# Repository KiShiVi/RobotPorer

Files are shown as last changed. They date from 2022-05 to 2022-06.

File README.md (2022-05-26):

# RobotPourer
Проект робота разливайки на Arduino. 

## Модель сборки

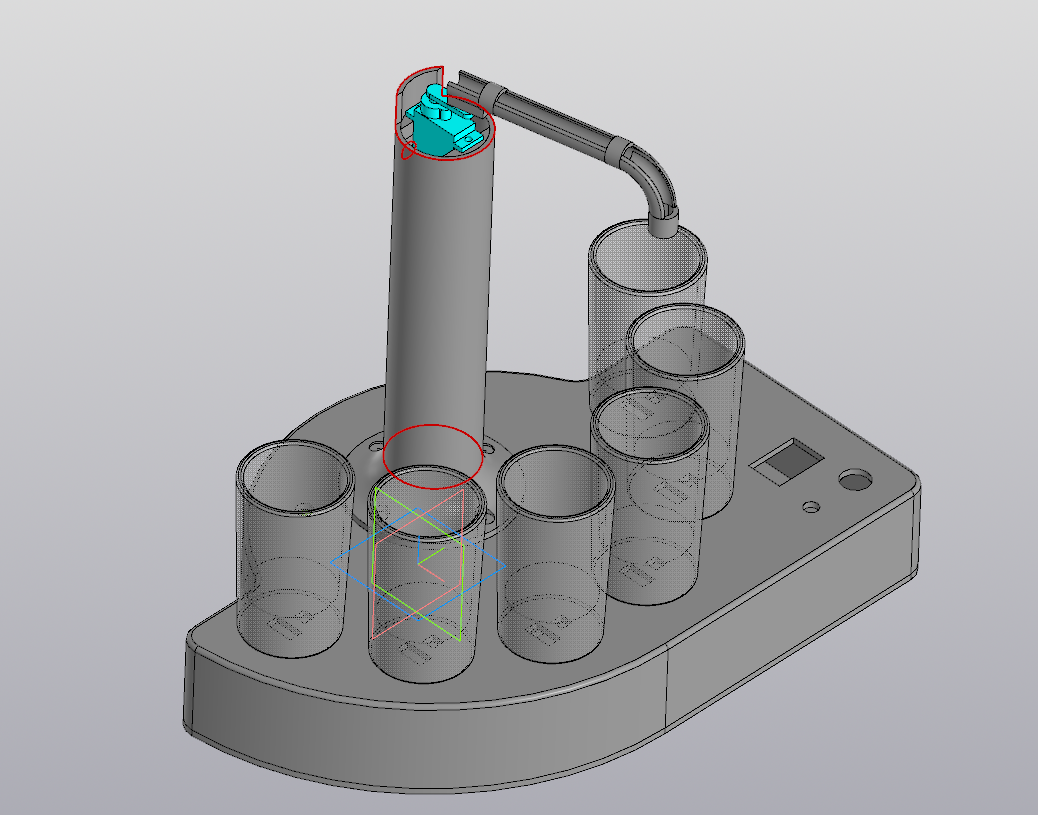
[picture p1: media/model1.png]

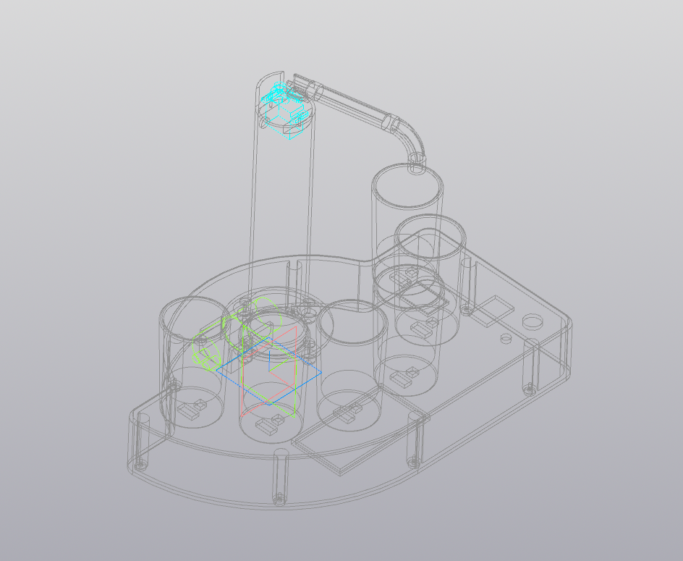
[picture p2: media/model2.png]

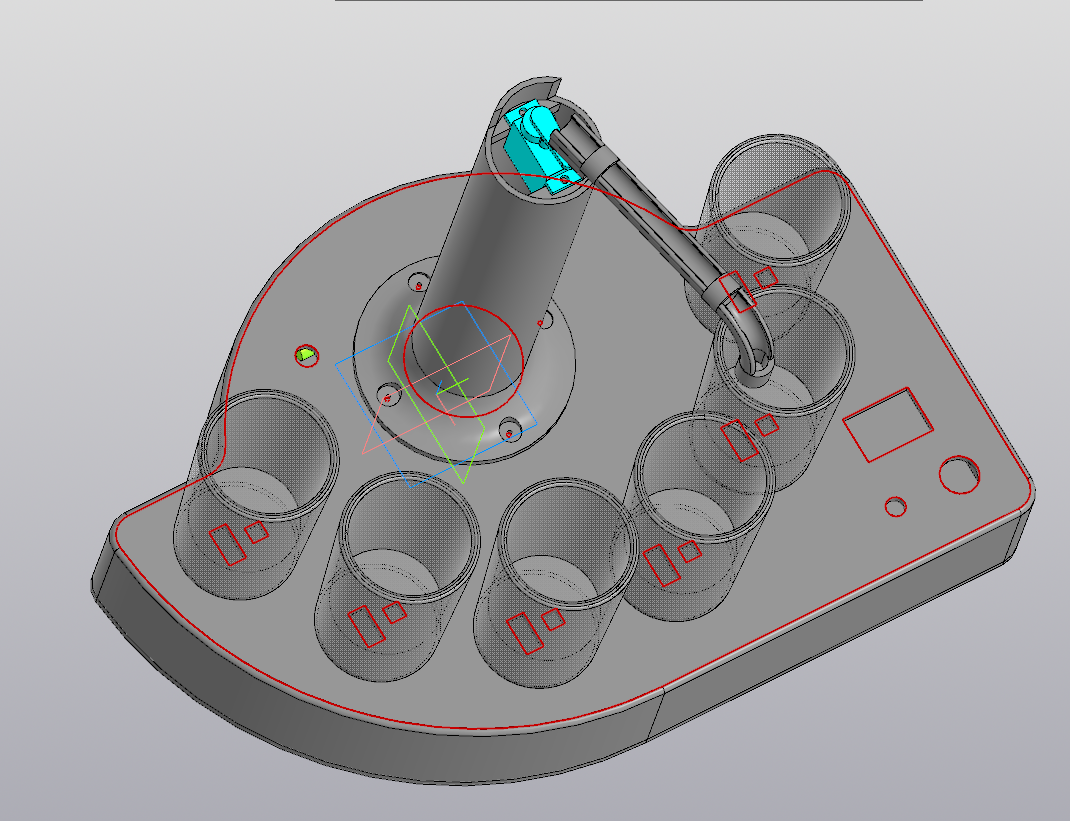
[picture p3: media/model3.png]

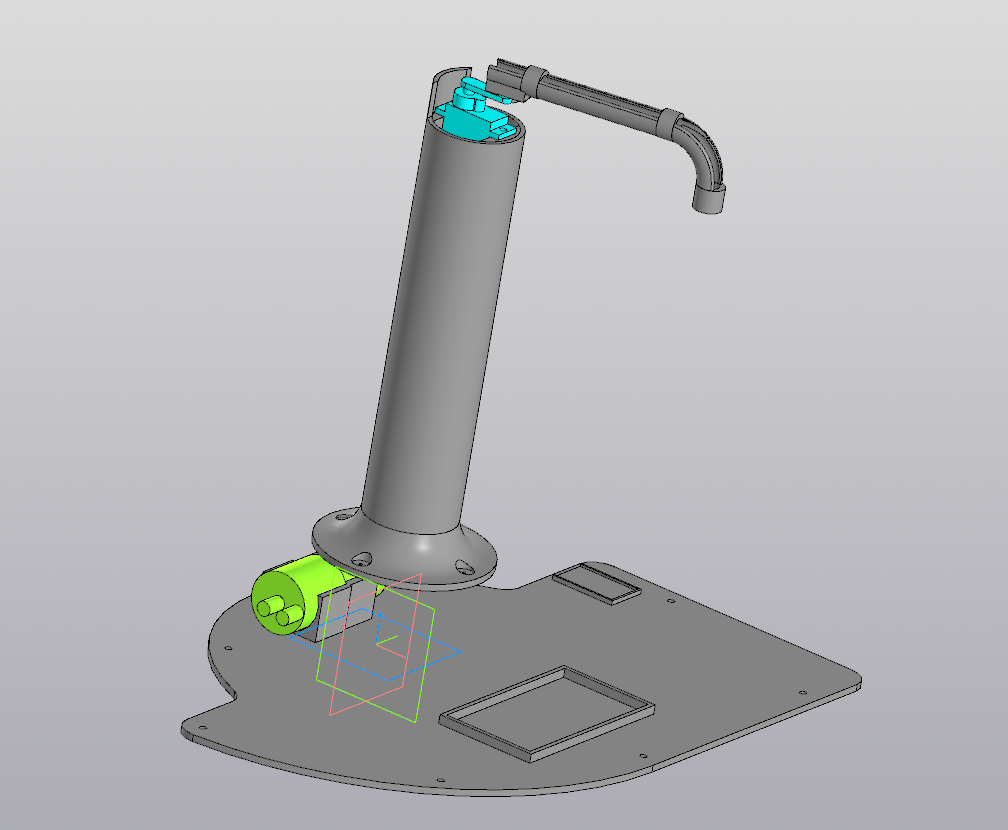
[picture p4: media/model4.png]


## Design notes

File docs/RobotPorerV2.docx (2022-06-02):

МИНОБРНАУКИ РОССИИ

САНКТ-ПЕТЕРБУРГСКИЙ ГОСУДАРСТВЕННЫЙ

ЭЛЕКТРОТЕХНИЧЕСКИЙ УНИВЕРСИТЕТ

«ЛЭТИ» ИМ. В.И. УЛЬЯНОВА (ЛЕНИНА)

Кафедра САПР

ОТЧЕТ

по курсовой работе

по дисциплине «Проектирование цифровых устройств»

Тема: Проектирование и реализация "робота-диспесора"

Студент гр. 9302 | | Тарабурин А.П.
Студент гр. 9302 | | Давтян С.Д.
Преподаватель | | Рыбин В.Г.

Санкт-Петербург

2022

АННОТАЦИЯ

Данная работа включает проектирование и реализацию «робота-диспенсора». В работе были использованы методы проектирование корпусов и схем, а также написан программный код для цифрового устройства. Кроме того, были доработаны и реализованы различные детали по улучшению работы данного робота.

В итоге корпус цифрового устройства был напечатан на 3D принтере, запрограммирован микроконтроллер, распаяна схема и собран робот.

ANNOTATION

This work includes the design and implementation of a "dispenser robot". The methods of designing cases and circuits were used in the work, and the program code for a digital device was written. In addition, various details have been finalized and implemented to improve the operation of this robot.

As a result, the body of the digital device was printed on a 3D printer, the microcontroller was programmed, the circuit was soldered, and the robot was assembled.

ОГЛАВЛЕНИЕ

# Цель работы

Изучить методы проектирование корпусов и схем, и научиться писать программный код для цифровых устройств

# Исходное задание

Необходимо реализовать цифровое устройство «робот-диспенсора», который будет разливать жидкость по сосудам, поставленным на обозначенные слоты со световой индикацией статусов. В роботе должны быть обозначены несколько режимов работы: автоматический, при котором разлив происходит без подтверждения пользователя; ручной, в котором разлив происходит только по нажатию кнопки, в выставленные рюмки; режим сервиса для отладки. Обеспечить пользователя информацией, которая будет водиться на OLED экран.

# Ход выполнения работы

# Принцип работы цифрового устройства

Робот-диспенсор (Рисунок 1) состоит из 4 частей. Отдельно были спроектированы корпус, крышка, стойка и краник. Каждая часть имеет свои особенности. Робот был собран с помощью соединения этих деталей.

Корпус содержит в себе множество отверстий. Под каждым слотом для рюмки есть по два отверстия, которые предназначены для адресного светодиода и концевика. Также отдельно есть отверстие прямоугольной формы для экрана и два круглых отверстия для энкодера и кнопки. Вдоль границ корпуса есть множество отверстий, которые предназначены для крепления крышки. Также есть два смежных отверстия: одно из них для стойки, другое – для прохождения сервопривода и силиконовой трубки. Силиконовая трубка через данное отверстие будет проходить к кранику (Рисунок 2).

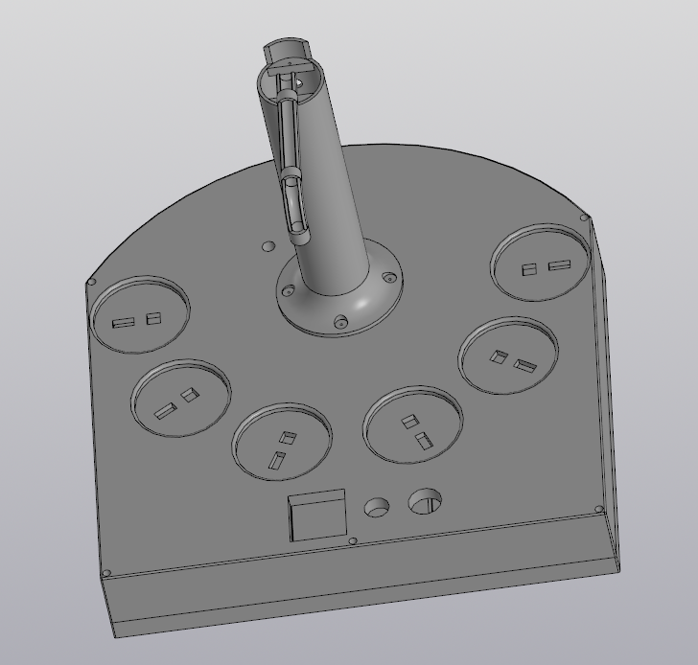
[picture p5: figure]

Рисунок 1. Робот-диспесор

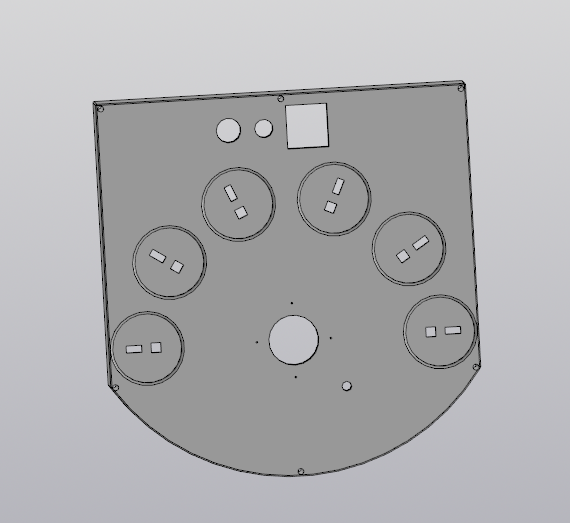
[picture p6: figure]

Рисунок 2. Корпус робота-диспесора

Стойка прикрепляется к корпусу. Для этого на ней предусмотрены четыре отверстия. Сама по себе она представляет из себя цилиндрический объект, через который проходит силиконовая трубка. Сверху есть крепление для сервопривода (Рисунок 3).

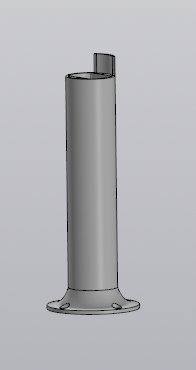
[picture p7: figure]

Рисунок 3. Стойка

Под корпусом находится крышка. Она крепится к корпусу с помощью саморезов. Для этого вдоль крышки сделаны отверстия. Также есть специальное крепление для водяной помпы (Рисунок 4).

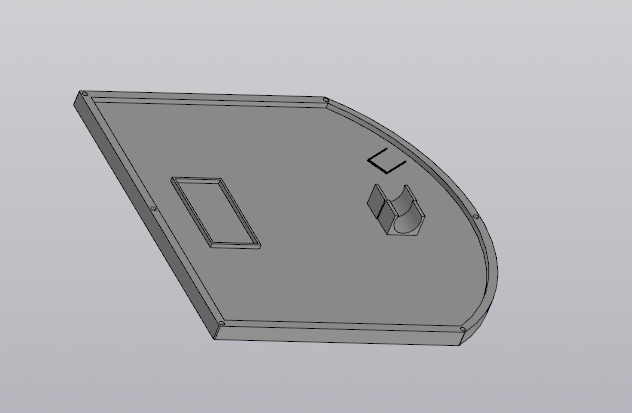
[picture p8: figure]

Рисунок 4. Крышка

Последняя часть робота-диспесора – краник. Он крепится к стойке. Для этого на нем сделаны отверстия. Через него будет поступать жидкость в рюмки (Рисунок 5).

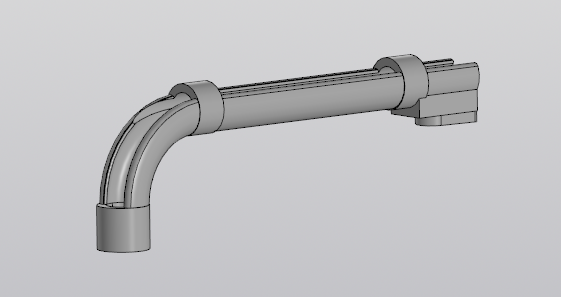
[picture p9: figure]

Рисунок 5. Краник

Описание схемы подключения

Схема подключения представлена на рисунках ниже (Рисунок 7, Рисунок 8, Рисунок 9, Рисунок 10)

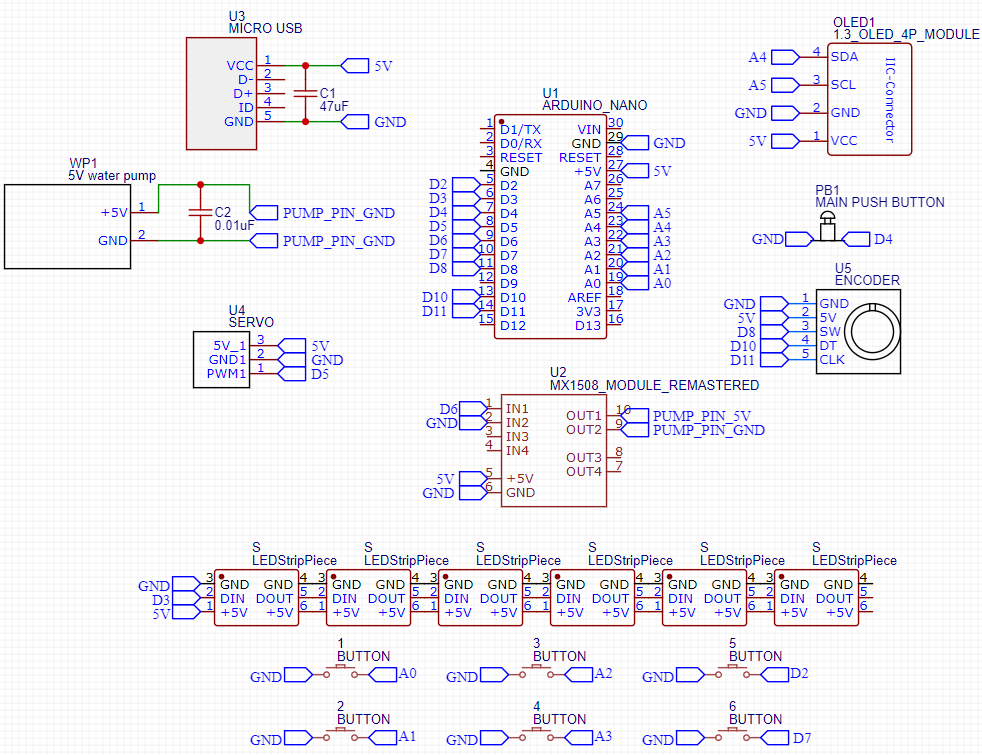
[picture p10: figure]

Рисунок 7

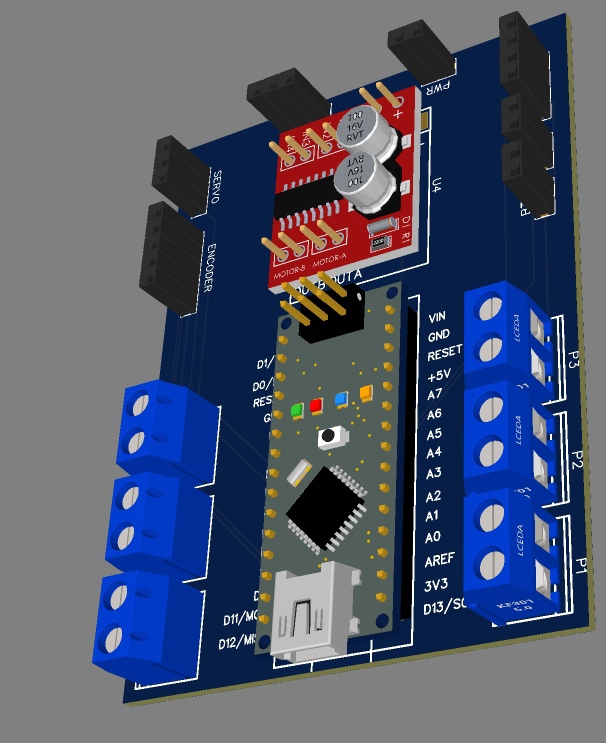
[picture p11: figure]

Рисунок 8

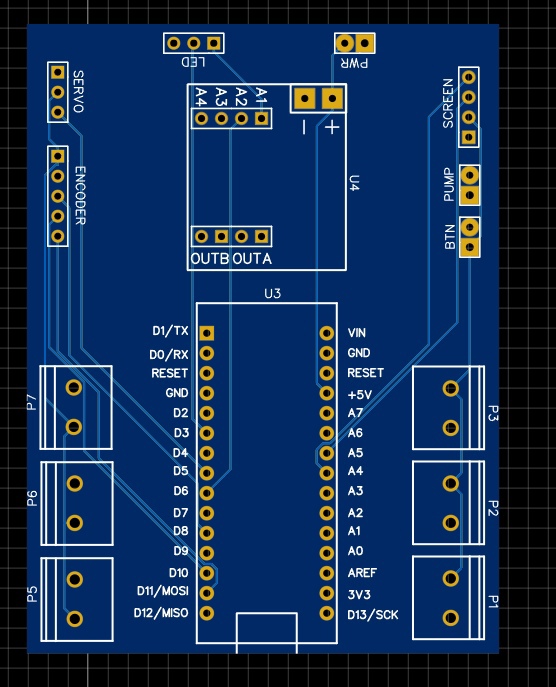
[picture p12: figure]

Рисунок 9

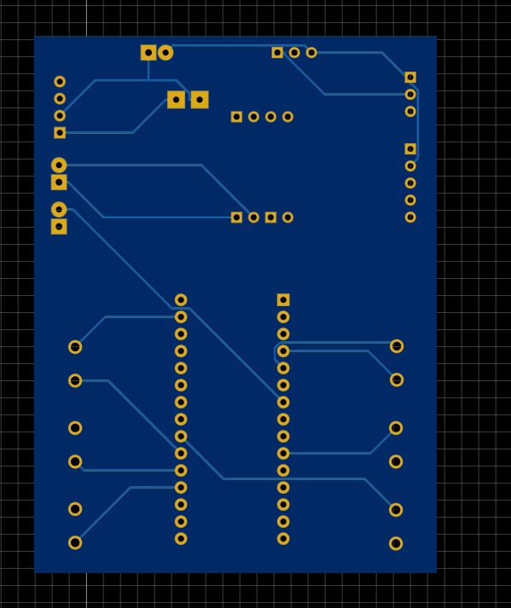
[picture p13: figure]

Рисунок 10

# Описание алгоритма работы устройства

Class Timer

Полями данного класса являются:

Интервал m_interval, хранящий значение, после которого можно перевести таймер в другое состояние;

Таймер m_timer показывает время начала работы в миллисекундах;

Состояние m_status отображает рабочее состояние таймера – true/false

Функция | Описание
Timer(uint32_t) | Конструктор от значения интервала
setInterval(uint32_t) | Установка значения интервала с проверкой на ненулевой аргумент
start() | Начало работы таймера, фиксирование текущего таймера и перевод состояния в рабочее
stop() | Завершение работы таймера, перевод в нерабочее состояние
boolean isReady() | Проверка готовности обрабатывания внешней функции с имеющимся интервалом и смещение существующего таймера к текущему значению времени, в диапазоне таймера
reset() | Обновление значения таймера до актуального
getState() | Получение состояния работы таймера

Class LedStrip

Полем класса ленты адресных светодиодов является массив leds класса CRGB, хранящий цвет подсветки имеющихся светодиодов

Функция | Описание
LedStrip () | Добавляем в массив LED_COUNT позиций светодиодов, выставляем яркость и изначальный цвет
ledOn( uint8_t pin, uint8_t r, uint8_t g, uint8_t b) | Выставляем цвет подсветки светодиоду в положении pin из цветовой модели RGB, параметры которой получаем из аргументов
ledOff( uint8_t) | Выставляем черный цвет подсветки светодиода в заданном положении, тем самым гася его

Class Pump

Полями класса помпы являются:

Таймер первоначальной задержки startDelayTimer, хранящий время задержки перед работой помпы;

Таймер окончательной задержки finishDelayTimer, хранящий время задержки после работы помпы;

Таймер окончания работы помпы finishTimer, показывающий время прекращения работы;

Состояние m_state, отображающее текущее рабочее состояние помпы BUSY/READY

Идентификатор пина m_pompPin, показывающий куда присоединено питание помпы

Функция | Описание
Pump(int) | Конструктор класса помпы от пина питания аппарата
pumpStart(uint32_t) | Старт работы помпы, перевод состояния в рабочее, установка заданного интервала для таймера окончания работы, запуск таймера первоначальной задержки
pumpStartWithoutTimer() | Начало работы помпы и перевод в рабочее состояние и запуск таймера первоначальной задержки
pumpStop( bool) | Остановка помпы, запуск таймера окончательной задержки и остановка остальных. Перевод в ожидающее состояние
getState() | Получение состояния работы помпы
isPouring() | Проверка накачивания жидкости в текущий момент при помощи проверки состояния таймера первоначальной задержки
isFinishedPoured () | Проверка завершения накачивания жидкости в текущий момент при помощи проверки состояния таймера окончания работы
pumpCheck() | Алгоритм приведения в работу помпы в зависимости от состояния одного из таймеров: При готовности таймера первоначальной задержки начинается накачивание жидкости При готовности таймера окончания работы останавливаем накачивание При готовности таймера окончательной задержки переводим помпу в режим ожидания

Class ServoCrane

Полями класса сервокраника являются:

Указатель на класс сервопривода Servo, хранящий методы работы с сервоприводами;

Значение m_currentAngle, хранящее текущий угол поворота краника относительно начальной позиции

Функция | Описание
ServoCrane (uint8_t) | Конструктор класса cервокраника с установкой пина питания сервопривода
rotate(uint8_t) | Поворот сервокраника на заданный угол с проверкой углов, выходящих за плоскость работы сервопривода
getCurrentAngle() | Получение текущего угла поворота сервокраника

Class Display

Поле класса дисплея является указатель на объект класса Adafruit_SSD1306, являющегося библиотечным классом для работы с нашим дисплеем.

Функция | Описание
Display () | Конструктор класса дисплея с очисткой, переводом курсора и заданием цвета шрифта. Выводит первоначальное приветствие
printRandToast() | Вывод случайного тоста из базы данных файла mem.hpp
printInfo(uint16_t volume, uint8_t mode) | Вывод количества наливаемого объема жидкости volume и текущего режима работы Робота-Наливайки mode

Class Slot

Полями класса слота для тары на корпусе робота являются:

Таймер работы кнопки подтверждения btnTimer, хранящий данные для ее работы;

Состояние кнопки btnState, обеспечивающее возможность ее нажатия;

Объекты ранее описанных классов сервокраника m_servo, помпы p_pump и ленты светодиодов p_ledStrip;

Номер пина концевика m_btnPin для обеспечения его питания;

Идентификатор слота m_slotID для передачи данных о нём вглубь алгоритма;

Значение угла поворота сервокраника к слоту m_slotAngle для поворота сервоприводом;

Состояние взаимодействия с тарой, размещенной на данном слоте, m_state - NO_GLASS, EMPTY, NEXT, PROCESS, READY;

Значение объема тары p_glassVolume, для регулирования процесса работы помпы.

Функция | Описание
Slot( LedStrip * ledStrip, Pump * pump, ServoCrane * servo, uint8_t btnPin, uint8_t slotID, uint8_t slotAngle, uint16_t * glassVolume ) | Конструктор класса слота с присвоением светодиода, помпы, сервокраника, установкой заданного номера пина концевика, идентификатора слота, угла поворота и объема тары. Состояние m_state изначально назначается NO_GLASS.
slotFirstCheck() | Первая проверка нажатия концевика слота. Включаем красный светодиод если рюмку только что поставили. Выключаем светодиод, если рюмку убрали. Меняем состояния.
slotSecondCheck() | Вторая проверка наливания стопки. Если статус слота PROCESS, ждем завершения таймера и перекрашиваем светодиод в зеленый. Меняем состояние на READY.
slotThirdCheck() | Третья проверка пустоты текущей рюмки. Если статус слота EMPTY поворачиваем сервокраник, в этот момент красим светодиод в синий, и начинаем наливать, попутно устанавливаем желтый цвет светодиоду. Меняем состояние на PROCESS.
getState() | Получение состояния слота.

Class Brain

Полями класса Brain, отвечающего за совмещение классов всех физических объектов и выполнение логики робота, являются:

Состояние робота m_mode, хранящее текущий режим работы робота MANUAL - ручной, AUTO - автоматический, SERVICE – сервисный;

Объем тары m_glassVolume, хранящий значение в миллилитрах;

Состояние m_status, показывающее текущую занятость робота BUSY, READY;

Логическая переменная m_toastFlag, отвечающее за возможность отображения тоста;

Логическая переменная isStarted, хранящий информацию о работе нового цикла робота;

Таймер начала работы p_starterTimer, отмеряющий время от запуска робота;

Значение текущего времени p_serviceTime, применяющееся для обработки нажатия сервисной кнопки;

Объекты ранее описанных классов сервокраника p_servo, помпы p_pump, ленты светодиодов p_ledStrip, дисплея p_display и массива слотов p_slots;

Указатели на библиотечные классы энкодера p_encoder и кнопки p_button;

Функция | Описание
Brain() | Конструктор по умолчанию с установкой ручного режима, объема тары 20 мл и всех прочих пинов питания
tick() | Срабатывает в loop .ino файла, здесь принимается решение о состоянии каждого слота, повороте сервокраника и отслеживании режима работы робота
changeAutoManualMode() | Изменение пользовательских режимов в зависимости от выбора
changeServiceMode() | Установка сервисного режима
incGlassVolume() | Увеличение объема тары от движения энкодера
decGlassVolume() | Уменьшение объема тары от движения энкодера
mainBtnPressed() | Обработчик длительного зажатия главной кнопки
mainBtnReleased() | Обработчик отпускания главной кнопки
mainBtnClick() | Обработчик нажатия главной кнопки
encClicked() | Обработчик нажатия энкодера, вызывающий отображение информации на главном экране

# Блок-схема алгоритма

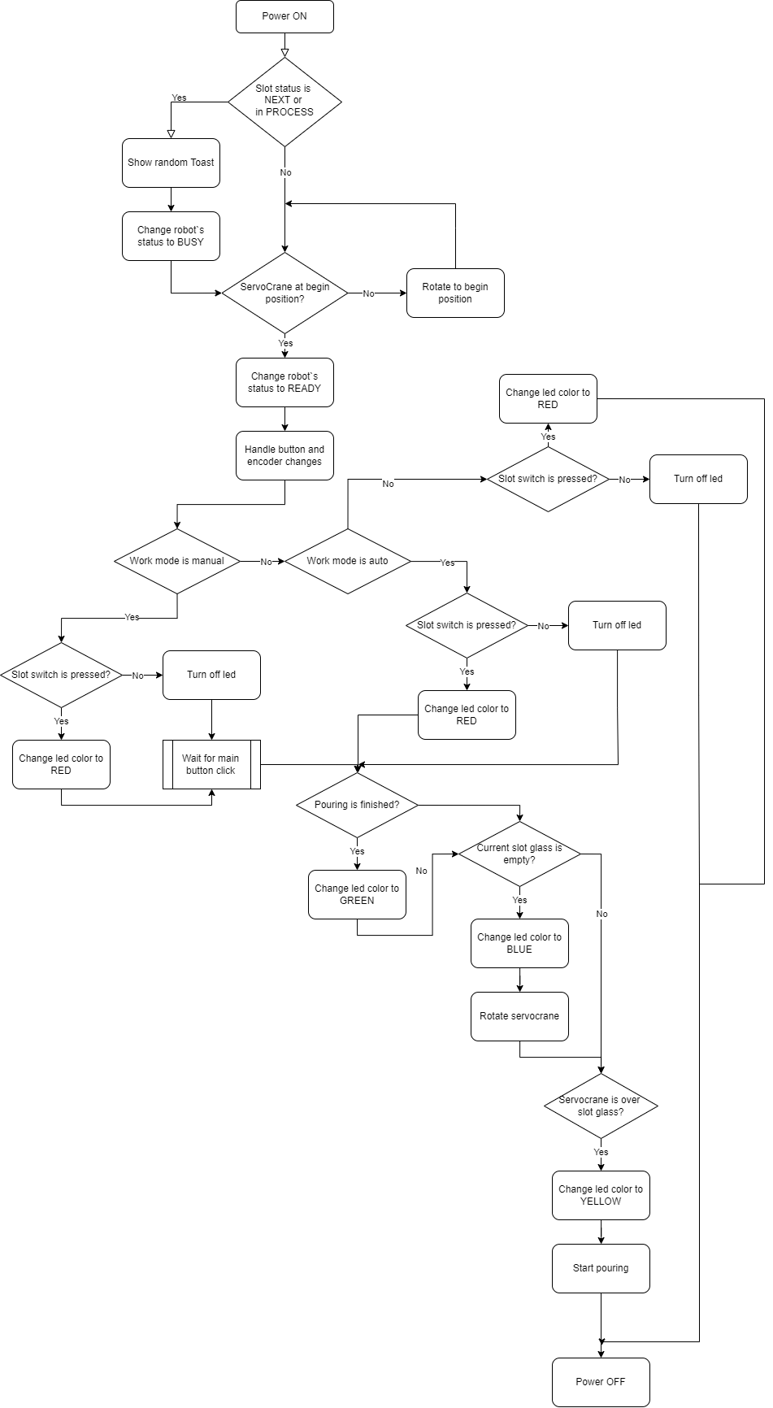
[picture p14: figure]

# ВЫВОД

В результате курсовой работы мы изучили методы проектирование корпусов и схем, и научились писать программный код для цифровых устройств.

А также мы реализовали цифровое устройство «робот-диспесора», который разливает жидкость в сосуды, поставленным на обозначенные слоты со световой индикацией статусов: красный, когда сосуд поставлен; синий, когда кран находиться над сосудом и скоро будет его наполнять; желтый, когда в сосуд наливается жидкость; зеленый, когда сосуд наполнили. В роботе обозначены несколько режимов работы: автоматический, при котором разлив происходит без подтверждения пользователя; ручной, в котором разлив происходит только по нажатию кнопки, в выставленные рюмки; режим сервиса для отладки. Еще мы обеспечили пользователя информацией, которая будет водиться на OLED экран, она включает в себя режим, угол движения крана, и тосты.

# СПИСОК ЛИТЕРАТУРЫ

1. Подбельский В. В. Язык C++ / В. В. Подбельский. — 3-е издание. — Москва : Финансы и статистика, 1998. — 560 c.
2. Макс Шлее Qt 5.10. Профессиональное программирование на C++ / Шлее Макс. — 1-е издание. — СПб : БХВ-Петербург, 2020. — 1072 c.
3. Герасимов, А. А. Самоучитель КОМПАС-3D V19 / А. А. Герасимов. — СПб : BHV, 2021. — 624 c. — Текст : непосредственный.

# ПРИЛОЖЕНИЕ

# Код программы

Timer.hpp

1. #ifndef TIMER_H
2. #define TIMER_H
4. /*
5. * Класс таймера
6. * Использован улучшенный алгоритм таймера на millis
7. * Обеспечивает кратные интервалы и защиту от пропусков и переполнений
8. *
9. */
10. class Timer
11. {
12. public:
13. Timer( uint32_t interval ); //!< Конструктор
14. void setInterval( uint32_t interval ); //!< Выставляет интервал срабатывания таймера
15. boolean isReady(); //!< Возвращает true, когда пришло время
16. void reset(); //!< Ручной сброс таймера
17. void stop(); //!< Остановка таймера
18. void start(); //!< Запуск таймера
19. bool getState();
21. private:
22. uint32_t m_timer = 0;
23. uint32_t m_interval = 0;
24. bool m_status = true;
25. };
27. Timer::Timer(uint32_t interval)
28. {
29. m_interval = interval;
30. m_timer = millis();
31. }
33. void Timer::setInterval(uint32_t interval)
34. {
35. m_interval = (interval == 0) ? 10 : interval;
36. }
38. void Timer::start()
39. {
40. m_status = true;
41. m_timer = millis();
42. }
44. void Timer::stop()
45. {
46. m_status = false;
47. }
49. boolean Timer::isReady()
50. {
51. uint32_t thisMls = millis();
52. if (m_status && thisMls - m_timer >= m_interval)
53. {
54. do
55. {
56. m_timer += m_interval;
57. if (m_timer < m_interval) break;
58. } while (m_timer < thisMls - m_interval);
59. return true;
60. }
61. else
62. {
63. return false;
64. }
65. }
67. void Timer::reset() {
68. m_timer = millis();
69. }
71. bool Timer::getState()
72. {
73. return m_status;
74. }
76. #endif

ledStrip.hpp

1. #ifndef LED_STRIP_H
2. #define LED_STRIP_H
4. #include "settings.hpp"
5. #include <FastLED.h>
7. /*
8. * Класс ленты адресных светодиодов
9. *
10. */
13. class LedStrip
14. {
15. public:
16. LedStrip(); //!< Конструктор
17. void ledOn( uint8_t pin, uint8_t r, uint8_t g, uint8_t b ); //!< Включить светодиод. pin - позиция светодиода. r/g/b - цвет (0-255)
18. void ledOff( uint8_t pin ); //!< Выключить светодиод. pin - позиция светодиода
20. private:
21. CRGB leds[LED_COUNT];
22. };
24. LedStrip::LedStrip()
25. {
26. FastLED.addLeds <WS2812, LED_PIN, GRB>(leds, LED_COUNT).setCorrection(TypicalLEDStrip);
27. FastLED.setBrightness( BRIGHTNESS );
28. for( int i = 0 ; i < LED_COUNT; ++i )
29. leds[i] = CRGB(0, 0, 0);
30. FastLED.show();
31. Serial.println(F("LedStrip init"));
32. }
34. void LedStrip::ledOn( uint8_t pin, uint8_t r, uint8_t g, uint8_t b )
35. {
36. //Serial.print( "Led ON (pin / R;G;B): " );
37. //Serial.print( pin );
38. //Serial.print( " / " );
39. //Serial.print( r );
40. //Serial.print( ";" );
41. //Serial.print( g );
42. //Serial.print( ";" );
43. //Serial.println( b );
45. leds[pin] = CRGB(r, g, b);
46. FastLED.show();
47. }
49. void LedStrip::ledOff( uint8_t pin )
50. {
51. //Serial.print( "Led OFF (pin): " );
52. //Serial.println( pin );
53. leds[pin] = CRGB(0, 0, 0);
54. FastLED.show();
55. }
57. #endif

Pump.hpp

1. #ifndef PUMP_H
2. #define PUMP_H
4. #include "settings.hpp"
5. #include "timer.hpp"
7. /*
8. * class Pump - Класс помпы
9. */
11. class Pump
12. {
13. public:
14. Pump( int pin ); //!< Конструктор. pin - Пин питания на помпу
15. void pumpStart( uint32_t milli = DEFAULT_FINISH_TIMER ); //!< Включить помпу на milli времени (мс)
16. void pumpStartWithoutTimer();
17. void pumpStop(bool justNow=false); //!< Выключить помпу
18. uint8_t getState(); //!< Получить состояние помпы (BUSY, READY)
19. bool isPouring();
20. bool isFinishedPoured();
22. void pumpCheck(); //!< Метод, который следует положить в loop(). Нужен для своевременного отключения по таймеру
24. private:
25. Timer * startDelayTimer;
26. Timer * finishTimer;
27. Timer * finishDelayTimer;
28. int m_pompPin;
29. enum{ BUSY = 0, READY = 1 } m_state;
30. };
32. Pump::Pump( int pin )
33. {
34. startDelayTimer = new Timer( DEFAULT_DELAY_TIMER );
35. finishTimer = new Timer( DEFAULT_FINISH_TIMER );
36. finishDelayTimer = new Timer( DEFAULT_DELAY_TIMER );
37. m_state = READY;
38. m_pompPin = pin;
39. Serial.println(F("Pump init"));
41. finishTimer->stop();
42. startDelayTimer->stop();
43. finishDelayTimer->stop();
44. }
46. void Pump::pumpStart( uint32_t milli )
47. {
48. if ( m_state == BUSY )
49. {
50. Serial.println(F("Pump BUSY"));
51. return;
52. }
53. m_state = BUSY;
54. startDelayTimer->start();
55. finishTimer->stop();
56. finishDelayTimer->stop();
57. finishTimer->setInterval( milli );
58. Serial.println(F("Pump PRE-START"));
59. }
61. void Pump::pumpStartWithoutTimer()
62. {
63. digitalWrite( m_pompPin, HIGH );
64. m_state = BUSY;
65. }
67. void Pump::pumpStop( bool justNow )
68. {
69. digitalWrite( m_pompPin, LOW );
70. Serial.println(F("Pump stoped"));
72. finishTimer->stop();
73. startDelayTimer->stop();
74. finishDelayTimer->start();
76. if ( justNow )
77. {
78. finishDelayTimer->stop();
79. m_state = READY;
80. }
81. }
83. uint8_t Pump::getState()
84. {
85. return m_state;
86. }
88. bool Pump::isPouring()
89. {
90. if ( startDelayTimer->getState() == false )
91. return true;
92. return false;
93. }
95. bool Pump::isFinishedPoured()
96. {
97. if ( finishTimer->getState() == false )
98. return true;
99. return false;
100. }
102. void Pump::pumpCheck()
103. {
104. if ( startDelayTimer->isReady() )
105. {
106. startDelayTimer->stop();
107. finishTimer->start();
108. finishDelayTimer->stop();
110. digitalWrite( m_pompPin, HIGH );
111. Serial.println(F("Pump started"));
112. }
114. if ( finishTimer->isReady() )
115. pumpStop();
117. if ( finishDelayTimer->isReady() )
118. {
119. startDelayTimer->stop();
120. finishTimer->stop();
121. finishDelayTimer->stop();
122. m_state = READY;
123. }
124. }
126. #endif

servoCrane.hpp

1. #ifndef SERVO_CRANE_H
2. #define SERVO_CRANE_H
4. #include <Servo.h>
6. class ServoCrane
7. {
8. public:
9. ServoCrane( uint8_t pin );
10. void rotate( uint8_t angle );
11. uint8_t getCurrentAngle();
12. private:
13. Servo * p_servo;
14. uint8_t m_currentAngle;
15. };
17. ServoCrane::ServoCrane( uint8_t pin )
18. {
19. p_servo = new Servo();
20. m_currentAngle = 180;
21. p_servo->attach( pin );
22. p_servo->write( m_currentAngle );
24. Serial.println(F("ServoCrane init"));
25. }
27. void ServoCrane::rotate( uint8_t angle )
28. {
29. if ( angle > 180 || angle < 0 )
30. return;
31. p_servo->write( angle );
32. m_currentAngle = angle;
33. Serial.println("ServoCrane rotate to " + angle);
34. }
36. uint8_t ServoCrane::getCurrentAngle()
37. {
38. return m_currentAngle;
39. }
43. #endif

Display.hpp

1. #ifndef DISPLAY_H
2. #define DISPLAY_H
4. #include "mem.hpp"
5. #include <Adafruit_GFX.h>
6. #include <Adafruit_SSD1306.h>
8. String utf8rus(String source);
9. //String printPGM(byte idx);
11. class Display
12. {
13. public:
14. Display();
15. void printRandToast();
16. void printInfo( uint16_t volume, uint8_t mode );
17. void printInfo( uint32_t volume );
18. private:
19. Adafruit_SSD1306 * display;
20. };
22. Display::Display()
23. {
24. display = new Adafruit_SSD1306(128, 32, &Wire);
25. display->begin(SSD1306_SWITCHCAPVCC, 0x3C);
26. display->clearDisplay();
27. display->display();
29. Serial.println(F("Display init"));
31. display->setTextSize(2);
32. display->setTextColor(SSD1306_WHITE);
33. display->setCursor(0,0);
34. display->println(utf8rus("Робот\nРазливайка"));
35. display->display();
36. }
38. void Display::printRandToast()
39. {
40. display->setTextSize(2);
41. display->clearDisplay();
42. display->display();
43. display->setCursor(0,0);
44. display->println(utf8rus(printPGM(random(0, 34))));
45. display->display();
46. }
48. void Display::printInfo( uint16_t volume, uint8_t mode )
49. {
50. display->setTextSize(4);
51. display->clearDisplay();
52. display->display();
53. display->setCursor(0,0);
54. display->println( volume );
55. display->setCursor(100,0);
57. if ( mode == 0 )
58. display->println( "M" );
59. else if ( mode == 1 )
60. display->println( "A" );
61. else if ( mode == 2 )
62. display->println( "S" );
64. display->display();
65. }
67. void Display::printInfo( uint32_t volume )
68. {
69. display->setTextSize(4);
70. display->clearDisplay();
71. display->display();
72. display->setCursor(0,0);
73. display->println( volume );
74. display->display();
75. }
78. String utf8rus(String source)
79. {
80. int i,k;
81. String target;
82. unsigned char n;
83. char m[2] = { '0', '\0' };
85. k = source.length(); i = 0;
87. while (i < k) {
88. n = source[i]; i++;
90. if (n >= 0xC0) {
91. switch (n) {
92. case 0xD0: {
93. n = source[i]; i++;
94. if (n == 0x81) { n = 0xA8; break; }
95. if (n >= 0x90 && n <= 0xBF) n = n + 0x30;
96. break;
97. }
98. case 0xD1: {
99. n = source[i]; i++;
100. if (n == 0x91) { n = 0xB8; break; }
101. if (n >= 0x80 && n <= 0x8F) n = n + 0x70;
102. break;
103. }
104. }
105. }
106. m[0] = n; target = target + String(m);
107. }
108. return target;
109. }
111. #endif

Display_debug.hpp

1. #ifndef DISPLAY_H
2. #define DISPLAY_H
4. #include "mem.hpp"
6. String utf8rus(String source);
7. String printPGM(byte idx);
9. class Display
10. {
11. public:
12. Display();
13. void printRandToast();
14. void printInfo( uint16_t volume, uint8_t mode );
15. };
17. Display::Display()
18. {
19. Serial.println(F("Display init"));
20. Serial.println(F("Робот\nРазливайка"));
21. }
23. void Display::printRandToast()
24. {
25. Serial.println( printPGM(random( 0, 20 ) ) );
26. }
28. void Display::printInfo( uint16_t volume, uint8_t mode )
29. {
30. String res;
31. res = volume;
32. res += " ";
34. if ( mode == 0 )
35. res += "M";
36. else if ( mode == 1 )
37. res += "A";
38. else if ( mode == 2 )
39. res += "S";
41. Serial.println( res );
42. }
45. void Display::printInfo( uint32_t volume )
46. {
47. Serial.println( volume );
48. }
51. String utf8rus(String source)
52. {
53. int i,k;
54. String target;
55. unsigned char n;
56. char m[2] = { '0', '\0' };
58. k = source.length(); i = 0;
60. while (i < k) {
61. n = source[i]; i++;
63. if (n >= 0xC0) {
64. switch (n) {
65. case 0xD0: {
66. n = source[i]; i++;
67. if (n == 0x81) { n = 0xA8; break; }
68. if (n >= 0x90 && n <= 0xBF) n = n + 0x30;
69. break;
70. }
71. case 0xD1: {
72. n = source[i]; i++;
73. if (n == 0x91) { n = 0xB8; break; }
74. if (n >= 0x80 && n <= 0x8F) n = n + 0x70;
75. break;
76. }
77. }
78. }
79. m[0] = n; target = target + String(m);
80. }
81. return target;
82. }
84. #endif

Slot.hpp

1. #ifndef SLOT_H
2. #define SLOT_H
4. #include "timer.hpp"
5. #include "servocrane.hpp"
6. #include "pump.hpp"
7. #include "ledstrip.hpp"
9. class Slot
10. {
11. public:
12. Slot( LedStrip * ledStrip, Pump * pump, ServoCrane * servo, uint8_t btnPin, uint8_t slotID, uint8_t slotAngle, uint16_t * glassVolume );
13. void slotFirstCheck();
14. void slotSecondCheck();
15. void slotThirdCheck();
16. uint8_t getState();
18. private:
19. Timer * btnTimer;
20. bool btnState;
21. ServoCrane * m_servo;
22. Pump * p_pump;
23. LedStrip * p_ledStrip; //!< Указатель на сервис ленты светодиодов
24. uint8_t m_btnPin; //!< Номер пина концевика
25. uint8_t m_slotID; //!< ID слота. Должен совпадать с индексом светодиода
26. uint8_t m_slotAngle; //!< Угол расположения слота (0-180)
27. enum{ NO_GLASS, EMPTY, NEXT, PROCESS, READY } m_state; //!< Статус слота
28. uint16_t * p_glassVolume;
29. };
31. Slot::Slot( LedStrip * ledStrip, Pump * pump, ServoCrane * servo, uint8_t btnPin, uint8_t slotID, uint8_t slotAngle, uint16_t * glassVolume )
32. {
33. btnTimer = new Timer( 100 );
34. btnState = false;
35. p_ledStrip = ledStrip;
36. p_pump = pump;
37. m_servo = servo;
38. m_btnPin = btnPin;
39. m_slotID = slotID;
40. m_slotAngle = slotAngle;
41. m_state = NO_GLASS;
42. p_glassVolume = glassVolume;
43. }
45. void Slot::slotFirstCheck()
46. {
47. /*
48. * Этап #1. Проверяем нажатие концевика. Включаем красный светодиод если рюмку только
49. * что поставили. Выключаем светодиод, если рюмку убрали. В ручном режиме этот режим нужно включить в loop отдельно,
50. * чтобы светодиоды закагарились красным до начала разлива
51. *
52. */
53. // Если концевик НЕ нажат
55. if ( btnTimer->isReady() )
56. btnState = digitalRead( m_btnPin );
58. if ( btnState )
59. {
60. // У сервопривода будет поле текущего угла. Нужно проверить - если угол серво равен углу слота и статус слота = PROCESS, значит стопаем помпу
61. if ( m_servo->getCurrentAngle() == m_slotAngle && ( m_state == PROCESS || m_state == NEXT ) )
62. {
63. p_pump->pumpStop( false );
64. }
66. if ( m_state != NO_GLASS )
67. {
68. m_state = NO_GLASS;
69. p_ledStrip->ledOff( m_slotID );
70. }
71. }
72. // Если концевик нажат
73. else if ( !btnState )
74. {
75. if ( m_state == NO_GLASS )
76. {
77. m_state = EMPTY;
78. p_ledStrip->ledOn( m_slotID, 255, 0, 0 );
79. }
80. }
81. }
83. void Slot::slotSecondCheck()
84. {
85. /*
86. * Этап #2. После первой проверки проверяем статус. Если рюмка налита красим светодиод в зеленый.
87. *
88. */
90. if ( m_state == PROCESS && p_pump->isFinishedPoured() )
91. {
92. m_state = READY;
93. p_ledStrip->ledOn( m_slotID, 0, 255, 0 );
94. }
96. }
98. void Slot::slotThirdCheck()
99. {
100. /*
101. * Этап #3. После второй проверки проверяем статус. Если рюмка пустует - пытаемся запросить серво и помпу налить в нее.
102. *
103. */
104. if ( m_state == EMPTY && p_pump->getState() != 0 /* m_servo->getState() != BUSY */ )
105. {
106. m_state = NEXT;
107. m_servo->rotate( m_slotAngle );
108. p_pump->pumpStart( ONE_HUNDRED_PER_SECOND / 100 * (*p_glassVolume) );
109. p_ledStrip->ledOn( m_slotID, 0, 0, 255 );
110. }
112. if ( m_state == NEXT && p_pump->isPouring() )
113. {
114. m_state = PROCESS;
115. p_ledStrip->ledOn( m_slotID, 255, 255, 0 );
116. }
118. }
120. uint8_t Slot::getState()
121. {
122. return m_state;
123. }
125. #endif

Brain.hpp

1. #ifndef BRAIN_H
2. #define BRAIN_H
4. #include "timer.hpp"
5. #include "settings.hpp"
6. #include <EncButton.h>
8. #include "slot.hpp"
9. #include "servocrane.hpp"
10. #include "pump.hpp"
11. #include "ledstrip.hpp"
12. #include "display.hpp"
16. const uint8_t BTN_SLOT_PINS[SLOT_COUNT] { A0, A1, A2, A3, 2, 7 };
17. const uint8_t SLOT_IDS[SLOT_COUNT] { 0, 1, 2, 3, 4, 5 };
18. const uint8_t SLOT_ANGLES[SLOT_COUNT] { 175, 143, 109, 71, 35, 5 };
20. class Brain
21. {
22. public:
23. Brain();
24. void tick();
25. private:
26. void changeAutoManualMode();
27. void changeServiceMode();
28. void incGlassVolume();
29. void decGlassVolume();
30. void mainBtnPressed();
31. void mainBtnReleased();
32. void mainBtnClick();
33. void encClicked();
35. enum{MANUAL, AUTO, SERVICE} m_mode;
36. uint16_t m_glassVolume;
37. enum{ BUSY, READY } m_status;
38. enum{ STARTED, FINISHED } m_manualModeFlag;
39. bool m_toastFlag;
41. bool isStarted;
42. Timer * p_starterTimer;
43. uint32_t p_serviceTime;
44. ServoCrane * p_servo;
45. Pump * p_pump;
46. LedStrip * p_ledStrip;
47. Slot ** p_slots;
48. Display * p_display;
49. EncButton<EB_TICK, ENC_A_PIN, ENC_B_PIN, ENC_BTN_PIN> * p_encoder;
50. EncButton<EB_TICK, MAIN_BTN_PIN> * p_button;
51. };
53. Brain::Brain()
54. {
55. p_starterTimer = new Timer( 3000 );
56. isStarted = false;
58. m_mode = MANUAL;
59. m_glassVolume = 20;
60. m_toastFlag = false;
61. p_servo = new ServoCrane( SERVO_PIN );
62. p_pump = new Pump( PUMP_PIN );
63. p_ledStrip = new LedStrip();
64. p_slots = new Slot * [SLOT_COUNT];
66. for ( int i = 0; i < SLOT_COUNT; ++i )
67. p_slots[i] = new Slot( p_ledStrip, p_pump, p_servo, BTN_SLOT_PINS[i], SLOT_IDS[i], SLOT_ANGLES[i], &m_glassVolume );
69. p_display = new Display();
71. p_encoder = new EncButton<EB_TICK, ENC_A_PIN, ENC_B_PIN, ENC_BTN_PIN>;
72. p_button = new EncButton<EB_TICK, MAIN_BTN_PIN>;
74. m_manualModeFlag = FINISHED;
75. }
77. void Brain::tick()
78. {
79. if ( !isStarted )
80. {
81. isStarted = p_starterTimer->isReady();
82. return;
83. }
85. m_status = READY;
86. for ( int i = 0; i < SLOT_COUNT; ++i )
87. if ( p_slots[i]->getState() == 2 || p_slots[i]->getState() == 3 )
88. {
89. m_status = BUSY;
90. m_manualModeFlag = STARTED;
91. if ( !m_toastFlag )
92. p_display->printRandToast();
93. m_toastFlag = true;
94. break;
95. }
97. if ( m_status == READY && p_servo->getCurrentAngle() != 180 && m_mode != SERVICE && p_pump->getState() != 0 )
98. p_servo->rotate( 180 );
100. if ( m_status == READY && p_servo->getCurrentAngle() == 180 && m_mode != SERVICE && p_pump->getState() != 0 )
101. {
102. m_manualModeFlag = FINISHED;
103. m_toastFlag = false;
104. }
106. p_encoder->tick();
107. p_button->tick();
108. p_pump->pumpCheck();
110. if ( m_status == READY )
111. {
112. if ( p_encoder->rightH() || p_encoder->leftH() )
113. changeAutoManualMode();
114. else if ( p_encoder->held() )
115. changeServiceMode();
116. else if ( p_encoder->right() )
117. incGlassVolume();
118. else if ( p_encoder->left() )
119. decGlassVolume();
120. else if ( p_encoder->click() )
121. encClicked();
122. else if ( p_button->press() )
123. mainBtnPressed();
124. else if ( p_button->release() )
125. mainBtnReleased();
126. else if ( p_button->click() )
127. mainBtnClick();
128. }
130. if ( m_mode == MANUAL )
131. {
132. for ( int i = 0; i < SLOT_COUNT; ++i )
133. p_slots[i]->slotFirstCheck();
134. if ( m_manualModeFlag == STARTED )
135. {
136. for ( int i = 0; i < SLOT_COUNT; ++i )
137. p_slots[i]->slotSecondCheck();
138. for ( int i = 0; i < SLOT_COUNT; ++i )
139. p_slots[i]->slotThirdCheck();
140. }
141. }
142. else if ( m_mode == AUTO )
143. {
144. for ( int i = 0; i < SLOT_COUNT; ++i )
145. p_slots[i]->slotFirstCheck();
146. for ( int i = 0; i < SLOT_COUNT; ++i )
147. p_slots[i]->slotSecondCheck();
148. for ( int i = 0; i < SLOT_COUNT; ++i )
149. p_slots[i]->slotThirdCheck();
150. }
151. else if ( m_mode == SERVICE )
152. {
153. for ( int i = 0; i < SLOT_COUNT; ++i )
154. p_slots[i]->slotFirstCheck();
155. }
156. }
158. void Brain::changeAutoManualMode()
159. {
160. Serial.println(F("Mode changed"));
161. if ( m_mode != SERVICE )
162. {
163. if ( m_mode == AUTO )
164. m_mode = MANUAL;
165. else if ( m_mode == MANUAL )
166. m_mode = AUTO;
168. p_display->printInfo( m_glassVolume, m_mode );
169. }
170. }
172. void Brain::changeServiceMode()
173. {
174. Serial.println(F("Mode changed"));
175. if ( m_mode == AUTO || m_mode == MANUAL)
176. {
177. m_mode = SERVICE;
178. p_display->printInfo( p_servo->getCurrentAngle(), m_mode );
179. }
180. else if ( m_mode == SERVICE && !p_button->hold() )
181. {
182. m_mode = MANUAL;
183. p_display->printInfo( m_glassVolume, m_mode );
184. }
185. }
187. void Brain::incGlassVolume()
188. {
189. if ( m_mode == AUTO || m_mode == MANUAL )
190. {
191. m_glassVolume = m_glassVolume >= 250 ? 250 : m_glassVolume + 1;
192. p_display->printInfo( m_glassVolume, m_mode );
193. }
195. else if ( m_mode == SERVICE )
196. {
197. p_servo->rotate( p_servo->getCurrentAngle() + 1 );
198. p_display->printInfo( p_servo->getCurrentAngle(), m_mode );
199. }
200. }
202. void Brain::decGlassVolume()
203. {
204. if ( m_mode == AUTO || m_mode == MANUAL )
205. {
206. m_glassVolume = m_glassVolume <= 5 ? 5 : m_glassVolume - 1;
207. p_display->printInfo( m_glassVolume, m_mode );
208. }
210. else if ( m_mode == SERVICE )
211. {
212. p_servo->rotate( p_servo->getCurrentAngle() - 1 );
213. p_display->printInfo( p_servo->getCurrentAngle(), m_mode );
214. }
215. }
217. void Brain::mainBtnPressed()
218. {
219. Serial.println(F( "MainBTN PRESSED" ) );
220. if ( m_mode == AUTO )
221. return;
222. else if ( m_mode == MANUAL )
223. return;
224. else if ( m_mode == SERVICE )
225. {
226. p_serviceTime = millis();
227. p_pump->pumpStartWithoutTimer();
228. }
229. }
231. void Brain::mainBtnReleased()
232. {
233. Serial.println(F("MainBTN RELEASED"));
234. if ( m_mode == SERVICE )
235. {
236. p_display->printInfo( ( millis() - p_serviceTime ) % 100000 );
237. p_pump->pumpStop();
238. }
239. }
241. void Brain::mainBtnClick()
242. {
243. if ( m_mode == MANUAL )
244. {
245. m_manualModeFlag = STARTED;
246. }
247. }
249. void Brain::encClicked()
250. {
251. if ( ( m_mode == AUTO || m_mode == MANUAL ) && m_manualModeFlag == FINISHED )
252. p_display->printInfo( m_glassVolume, m_mode );
254. else if ( m_mode == SERVICE && m_manualModeFlag == FINISHED )
255. p_display->printInfo( p_servo->getCurrentAngle(), m_mode );
256. }
258. #endif

Setting.hpp

1. #ifndef SETTINGS_H
2. #define SETTINGS_H
5. //Общая настройка
6. #define SLOT_COUNT 6
7. #define SERVO_PIN 5
8. #define PUMP_PIN 6
11. //Настройка элементов управления
12. #define MAIN_BTN_PIN 4
13. #define ENC_BTN_PIN 11
14. #define ENC_A_PIN 10
15. #define ENC_B_PIN 8
18. //Настройка светодиодной ленты
19. #define BRIGHTNESS 255 //!< Яркость светодиодов
20. #define LED_PIN 3 //!< Пин подключения светодиодной ленты
21. #define LED_COUNT 6 //!< Кол-во светодиодов в ленте
24. //Настройка помпы
25. #define DEFAULT_DELAY_TIMER 1500
26. #define DEFAULT_FINISH_TIMER 2000 //!< Время по умолчанию, которое будет отрабатывать мотор при pumpStart( uint32_t seconds )
27. #define ONE_HUNDRED_PER_SECOND 12900
30. #endif

Mem.hpp

1. #ifndef MEM_H
2. #define MEM_H
4. const char str1[] PROGMEM = " ЗА\n ЛЮБОВЬ";
5. const char str2[] PROGMEM = " ЧТОБЫ\n ВСЕ";
6. const char str3[] PROGMEM = " ЗА ВСЁ\n ХОРОШЕЕ";
7. const char str4[] PROGMEM = " ЗА\n ЗДОРОВЬЕ";
8. const char str5[] PROGMEM = " ЗА\n ДЕТЕЙ";
9. const char str6[] PROGMEM = "ЗА\nРОДИТЕЛЕЙ";
10. const char str7[] PROGMEM = " ЗА\n ДРУЖБУ";
11. const char str8[] PROGMEM = " БЫТЬ\n ДОБРУ";
12. const char str9[] PROGMEM = " ЗА МИР";
13. const char str10[] PROGMEM = " НЕ\n ЧОКАЯСЬ";
14. const char str11[] PROGMEM = " ЗА\n ЖИЗНЬ";
15. const char str12[] PROGMEM = " ЗА ДАМ";
16. const char str13[] PROGMEM = " ЗА\n РОССИЮ";
17. const char str14[] PROGMEM = " ЗА\n МУЖЧИН";
18. const char str15[] PROGMEM = " ЗА\n УДАЧУ";
19. const char str16[] PROGMEM = " ЗА НАС";
20. const char str17[] PROGMEM = " ЗА\n КРАСОТУ";
21. const char str18[] PROGMEM = " ЗА\n ДОБРОТУ";
22. const char str19[] PROGMEM = " ЗА\n ПОГОДУ";
23. const char str20[] PROGMEM = " ЗА\n ПРИРОДУ";
24. const char str21[] PROGMEM = " ЗА\n ХОЗЯИНА";
25. const char str22[] PROGMEM = " ЗА\n БУДУЩЕЕ";
26. const char str23[] PROGMEM = " ЗА\n ПАМЯТЬ";
27. const char str24[] PROGMEM = " ЗА\n ОТДЫХ";
28. const char str25[] PROGMEM = "ЗА\nНАСТРОЕНИЕ";
29. const char str26[] PROGMEM = " ЧТОБ\n СТОЯЛ";
30. const char str27[] PROGMEM = " ЗА\n ДОСТАТОК";
31. const char str28[] PROGMEM = " ЗА\n КОСМОС";
32. const char str29[] PROGMEM = " ЗА\n ТЕРПЕНИЕ";
33. const char str30[] PROGMEM = " ЗА\n МЕДВЕДЕЙ";
34. const char str31[] PROGMEM = " ЗА\n ЛОГИКУ";
35. const char str32[] PROGMEM = "ЗА\n ТРЕЗВОСТЬ";
36. const char str33[] PROGMEM = " ЗА\n УСПЕХ";
37. const char str34[] PROGMEM = " ЗА\n ПОБЕДУ";
39. const char* const names[] PROGMEM = {
40. str1, str2, str3, str4, str5,
41. str6, str7, str8, str9, str10,
42. str11, str12, str13, str14, str15,
43. str16, str17, str18, str19, str20,
44. str21, str22, str23, str24, str25,
45. str26, str27, str28, str29, str30,
46. str31, str32, str33, str34
47. };
49. String printPGM(byte idx) {
50. PGM_P p = pgm_read_word(names + idx);
51. char buf[strlen_P(p)];
52. strcpy_P(buf, p);
53. return String(buf);
54. }
56. #endif

Main.ino

1. #include "brain.hpp"
3. Brain * brain;
5. void setup() {
6. pinMode(A0, INPUT_PULLUP);
7. pinMode(A1, INPUT_PULLUP);
8. pinMode(A2, INPUT_PULLUP);
9. pinMode(A3, INPUT_PULLUP);
10. pinMode(2, INPUT_PULLUP);
11. pinMode(7, INPUT_PULLUP);
12. pinMode(4, INPUT_PULLUP);
13. pinMode(6, OUTPUT);
14. pinMode(3, OUTPUT);
15. pinMode(5, OUTPUT);
16. //digitalWrite(6, LOW);
18. Serial.begin(9600);
19. brain = new Brain();
20. }
22. void loop() {
23. brain->tick();
24. }
26. extern int __bss_end;
27. extern void *__brkval;
29. int memoryFree()
30. {
31. int freeValue;
32. if((int)__brkval == 0)
33. freeValue = ((int)&freeValue) - ((int)&__bss_end);
34. else
35. freeValue = ((int)&freeValue) - ((int)__brkval);
36. return freeValue;
37. }

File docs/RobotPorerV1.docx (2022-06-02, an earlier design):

МИНОБРНАУКИ РОССИИ

САНКТ-ПЕТЕРБУРГСКИЙ ГОСУДАРСТВЕННЫЙ

ЭЛЕКТРОТЕХНИЧЕСКИЙ УНИВЕРСИТЕТ

«ЛЭТИ» ИМ. В.И. УЛЬЯНОВА (ЛЕНИНА)

Кафедра САПР

ОТЧЕТ

по курсовой работе

по дисциплине «Проектирование цифровых устройств»

Тема: Проектирование и реализация "робота-диспенсера"

Студент гр. 9302 | | Ширнин К.В.
Студент гр. 9302 | | Кнауб К.В.
Преподаватель | | Рыбин В.Г.

Санкт-Петербург

2022

АННОТАЦИЯ

Данная работа включает проектирование и реализацию «робота-диспенсера». В работе были использованы методы проектирование корпусов и схем, а также написан программный код для цифрового устройства. Кроме того, были доработаны и реализованы различные детали по улучшению работы данного робота.

В итоге корпус цифрового устройства был напечатан на 3D принтере, запрограммирован микроконтроллер, распаяна схема и собран робот.

ANNOTATION

This work includes the design and implementation of a "dispenser robot". The methods of designing cases and circuits were used in the work, and the program code for a digital device was written. In addition, various details have been finalized and implemented to improve the operation of this robot.

As a result, the body of the digital device was printed on a 3D printer, the microcontroller was programmed, the circuit was soldered, and the robot was assembled.

ОГЛАВЛЕНИЕ

# Цель работы

Изучить методы проектирование корпусов и схем, и научиться писать программный код для цифровых устройств

# Исходное задание

Необходимо реализовать цифровое устройство «робот-диспенсер», который будет разливать жидкость по сосудам, поставленным на обозначенные слоты со световой индикацией статусов. В роботе должны быть обозначены несколько режимов работы: автоматический, при котором разлив происходит без подтверждения пользователя; ручной, в котором разлив происходит только по нажатию кнопки, в выставленные рюмки; режим сервиса для отладки. Обеспечить пользователя информацией, которая будет водиться на OLED экран.

# Ход выполнения работы

# Принцип работы цифрового устройства

# Описание корпуса

Для робота-диспенсер (Рисунок 1, Рисунок 2) был спроектирован следующий корпус. Он состоит из 4 частей: крышка, корпус, стойка, краник.

Корпус содержит в себе отверстия под энкодер, кнопку, экран. Также в каждом из слотов для рюмки есть отверстия под адресный светодиод и концевик. Также корпус содержит отверстие для стойки. Смежно с ним есть отверстие, через которое будут проходить провода для сервопривода и силиконовая трубка, которая будет идти к кранику. Внутри корпуса, рядом с отверстием для стойки, находится помпа. В корпусе есть крепления для крышки (Рисунок 3).

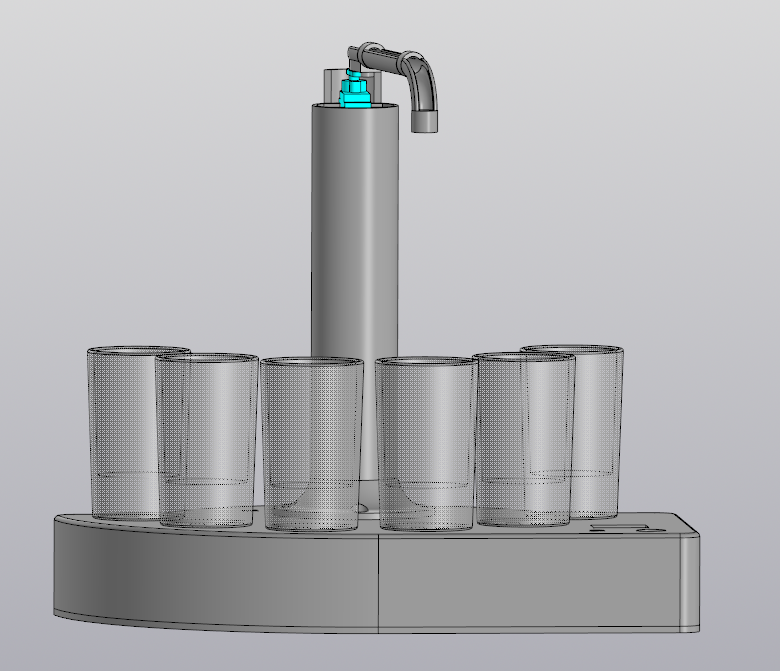
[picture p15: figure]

Рисунок 1. Робот-диспенсер

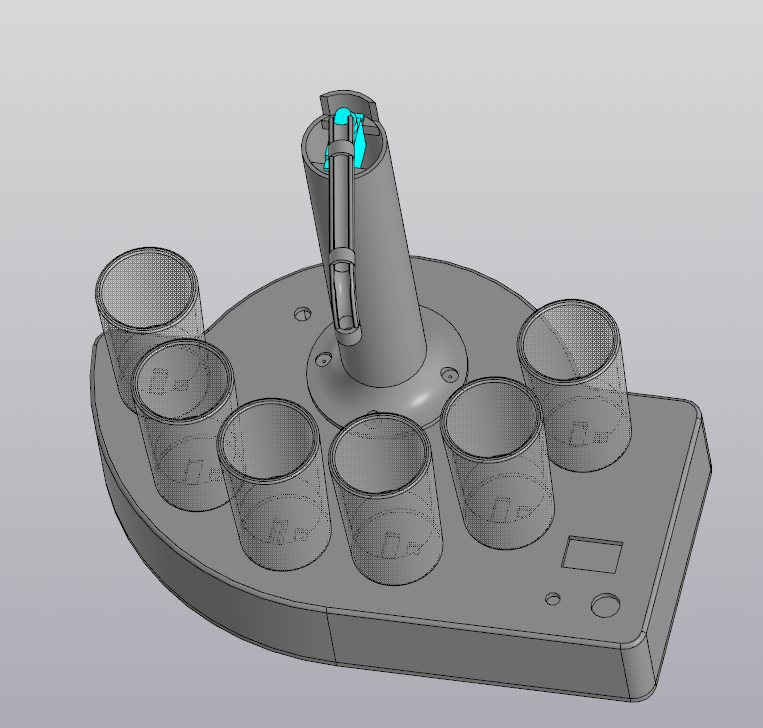
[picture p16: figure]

Рисунок 2. Робот-диспенсер

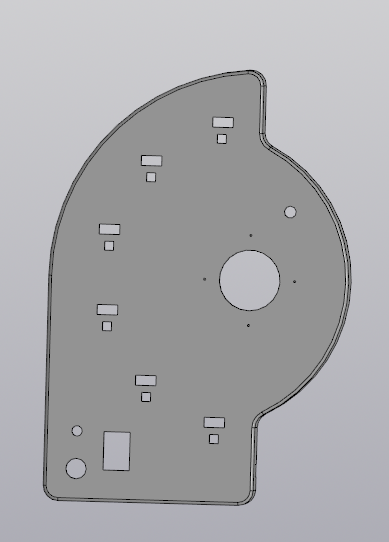
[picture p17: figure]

Рисунок 3. Корпус робота-диспенсера

Стойка представляет из себя полый цилиндрический объект с креплением для сервопривода наверху. Она имеет отверстия для крепления к корпусу (Рисунок 4).

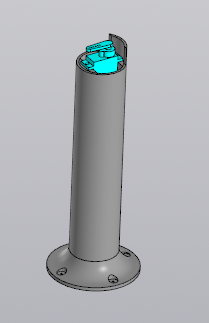
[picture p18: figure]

Рисунок 4. Стойка с прикрепленным сервоприводом

Крышка содержит в себе отверстия для ее крепления к корпусу. Во внутренней части она имеет специальное крепление для водяной помпы (Рисунок 5).

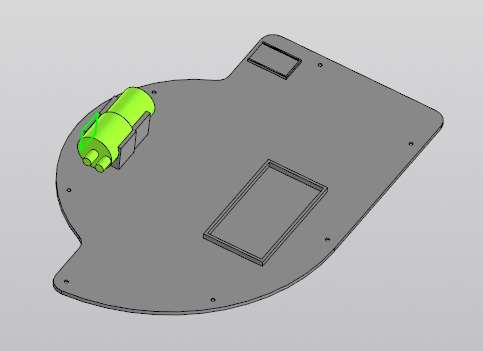
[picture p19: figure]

Рисунок 5. Крышка с прикрепленной водяной помпой

Краник имеет отверстия для его крепления к стойке. Также он имеет отверстие, через которое будет поступать жидкость в рюмки (Рисунок 6).

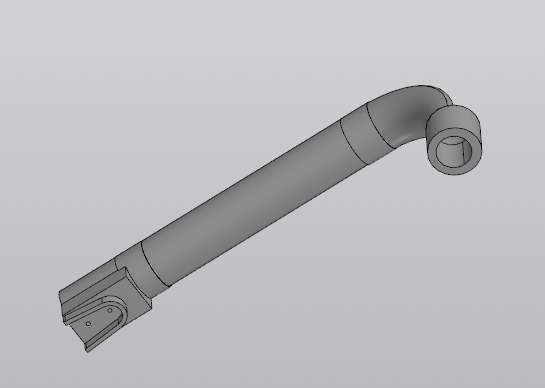
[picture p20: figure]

Рисунок 6. Краник

Описание схемы подключения

Схема подключения представлена на рисунках ниже (Рисунок 7, Рисунок 8, Рисунок 9, Рисунок 10)


Рисунок 7


Рисунок 8


Рисунок 9


Рисунок 10

# Описание алгоритма работы устройства

Class Timer

Полями данного класса являются:

Интервал m_interval, хранящий значение после которого можно перевести таймер в другое состояние;

Таймер m_timer показывает время начала работы в миллисекундах;

Состояние m_status отображает рабочее состояние таймера – true/false

Функция | Описание
Timer(uint32_t) | Конструктор от значения интервала
setInterval(uint32_t) | Установка значения интервала с проверкой на ненулевой аргумент
start() | Начало работы таймера, фиксирование текущего таймера и перевод состояния в рабочее
stop() | Завершение работы таймера, перевод в нерабочее состояние
boolean isReady() | Проверка готовности обрабатывания внешней функции с имеющимся интервалом и смещение существующего таймера к текущему значению времени, в диапазоне таймера
reset() | Обновление значения таймера до актуального
getState() | Получение состояния работы таймера

Class LedStrip

Полем класса ленты адресных светодиодов является массив leds класса CRGB, хранящий цвет подсветки имеющихся светодиодов

Функция | Описание
LedStrip () | Добавляем в массив LED_COUNT позиций светодиодов, выставляем яркость и изначальный цвет
ledOn( uint8_t pin, uint8_t r, uint8_t g, uint8_t b) | Выставляем цвет подсветки светодиоду в положении pin из цветовой модели RGB, параметры которой получаем из аргументов
ledOff( uint8_t) | Выставляем черный цвет подсветки светодиода в заданном положении, тем самым гася его

Class Pump

Полями класса помпы являются:

Таймер первоначальной задержки startDelayTimer, хранящий время задержки перед работой помпы;

Таймер окончательной задержки finishDelayTimer, хранящий время задержки после работы помпы;

Таймер окончания работы помпы finishTimer, показывающий время прекращения работы;

Состояние m_state, отображающее текущее рабочее состояние помпы BUSY/READY

Идентификатор пина m_pompPin, показывающий куда присоединено питание помпы

Функция | Описание
Pump(int) | Конструктор класса помпы от пина питания аппарата
pumpStart(uint32_t) | Старт работы помпы, перевод состояния в рабочее, установка заданного интервала для таймера окончания работы, запуск таймера первоначальной задержки
pumpStartWithoutTimer() | Начало работы помпы и перевод в рабочее состояние и запуск таймера первоначальной задержки
pumpStop( bool) | Остановка помпы, запуск таймера окончательной задержки и остановка остальных. Перевод в ожидающее состояние
getState() | Получение состояния работы помпы
isPouring() | Проверка накачивания жидкости в текущий момент при помощи проверки состояния таймера первоначальной задержки
isFinishedPoured () | Проверка завершения накачивания жидкости в текущий момент при помощи проверки состояния таймера окончания работы
pumpCheck() | Алгоритм приведения в работу помпы в зависимости от состояния одного из таймеров: При готовности таймера первоначальной задержки начинается накачивание жидкости При готовности таймера окончания работы останавливаем накачивание При готовности таймера окончательной задержки переводим помпу в режим ожидания

Class ServoCrane

Полями класса сервокраника являются:

Указатель на класс сервопривода Servo, хранящий методы работы с сервоприводами;

Значение m_currentAngle, хранящее текущий угол поворота краника относительно начальной позиции

Функция | Описание
ServoCrane (uint8_t) | Конструктор класса cервокраника с установкой пина питания сервопривода
rotate(uint8_t) | Поворот сервокраника на заданный угол с проверкой углов, выходящих за плоскость работы сервопривода
getCurrentAngle() | Получение текущего угла поворота сервокраника

Class Display

Поле класса дисплея является указатель на объект класса Adafruit_SSD1306, являющегося библиотечным классом для работы с нашим дисплеем.

Функция | Описание
Display () | Конструктор класса дисплея с очисткой, переводом курсора и заданием цвета шрифта. Выводит первоначальное приветствие
printRandToast() | Вывод случайного тоста из базы данных файла mem.hpp
printInfo(uint16_t volume, uint8_t mode) | Вывод количества наливаемого объема жидкости volume и текущего режима работы Робота-Наливайки mode

Class Slot

Полями класса слота для тары на корпусе робота являются:

Таймер работы кнопки подтверждения btnTimer, хранящий данные для ее работы;

Состояние кнопки btnState, обеспечивающее возможность ее нажатия;

Объекты ранее описанных классов сервокраника m_servo, помпы p_pump и ленты светодиодов p_ledStrip;

Номер пина концевика m_btnPin для обеспечения его питания;

Идентификатор слота m_slotID для передачи данных о нём вглубь алгоритма;

Значение угла поворота сервокраника к слоту m_slotAngle для поворота сервоприводом;

Состояние взаимодействия с тарой, размещенной на данном слоте, m_state - NO_GLASS, EMPTY, NEXT, PROCESS, READY;

Значение объема тары p_glassVolume, для регулирования процесса работы помпы.

Функция | Описание
Slot( LedStrip * ledStrip, Pump * pump, ServoCrane * servo, uint8_t btnPin, uint8_t slotID, uint8_t slotAngle, uint16_t * glassVolume ) | Конструктор класса слота с присвоением светодиода, помпы, сервокраника, установкой заданного номера пина концевика, идентификатора слота, угла поворота и объема тары. Состояние m_state изначально назначается NO_GLASS.
slotFirstCheck() | Первая проверка нажатия концевика слота. Включаем красный светодиод если рюмку только что поставили. Выключаем светодиод, если рюмку убрали. Меняем состояния.
slotSecondCheck() | Вторая проверка наливания стопки. Если статус слота PROCESS, ждем завершения таймера и перекрашиваем светодиод в зеленый. Меняем состояние на READY.
slotThirdCheck() | Третья проверка пустоты текущей рюмки. Если статус слота EMPTY поворачиваем сервокраник, в этот момент красим светодиод в синий, и начинаем наливать, попутно устанавливаем желтый цвет светодиоду. Меняем состояние на PROCESS.
getState() | Получение состояния слота.

Class Brain

Полями класса Brain, отвечающего за совмещение классов всех физических объектов и выполнение логики робота, являются:

Состояние робота m_mode, хранящее текущий режим работы робота MANUAL - ручной, AUTO - автоматический, SERVICE – сервисный;

Объем тары m_glassVolume, хранящий значение в миллилитрах;

Состояние m_status, показывающее текущую занятость робота BUSY, READY;

Логическая переменная m_toastFlag, отвечающее за возможность отображения тоста;

Логическая переменная isStarted, хранящий информацию о работе нового цикла робота;

Таймер начала работы p_starterTimer, отмеряющий время от запуска робота;

Значение текущего времени p_serviceTime, применяющееся для обработки нажатия сервисной кнопки;

Объекты ранее описанных классов сервокраника p_servo, помпы p_pump, ленты светодиодов p_ledStrip, дисплея p_display и массива слотов p_slots;

Указатели на библиотечные классы энкодера p_encoder и кнопки p_button;

Функция | Описание
Brain() | Конструктор по умолчанию с установкой ручного режима, объема тары 20 мл и всех прочих пинов питания
tick() | Срабатывает в loop .ino файла, здесь принимается решение о состоянии каждого слота, повороте сервокраника и отслеживании режима работы робота
changeAutoManualMode() | Изменение пользовательских режимов в зависимости от выбора
changeServiceMode() | Установка сервисного режима
incGlassVolume() | Увеличение объема тары от движения энкодера
decGlassVolume() | Уменьшение объема тары от движения энкодера
mainBtnPressed() | Обработчик длительного зажатия главной кнопки
mainBtnReleased() | Обработчик отпускания главной кнопки
mainBtnClick() | Обработчик нажатия главной кнопки
encClicked() | Обработчик нажатия энкодера, вызывающий отображение информации на главном экране

# Блок-схема алгоритма


# ВЫВОД

В результате курсовой работы мы изучили методы проектирование корпусов и схем, и научились писать программный код для цифровых устройств.

А также мы реализовали цифровое устройство «робот-диспенсер», который разливает жидкость в сосуды, поставленным на обозначенные слоты со световой индикацией статусов: красный, когда сосуд поставлен; синий, когда кран находиться над сосудом и скоро будет его наполнять; желтый, когда в сосуд наливается жидкость; зеленый, когда сосуд наполнили. В роботе обозначены несколько режимов работы: автоматический, при котором разлив происходит без подтверждения пользователя; ручной, в котором разлив происходит только по нажатию кнопки, в выставленные рюмки; режим сервиса для отладки. Еще мы обеспечили пользователя информацией, которая будет водиться на OLED экран, она включает в себя режим, угол движения крана, и тосты.

# СПИСОК ЛИТЕРАТУРЫ

1. Подбельский В. В. Язык C++ / В. В. Подбельский. — 3-е издание. — Москва : Финансы и статистика, 1998. — 560 c.
2. Макс Шлее Qt 5.10. Профессиональное программирование на C++ / Шлее Макс. — 1-е издание. — СПб : БХВ-Петербург, 2020. — 1072 c.
3. Герасимов, А. А. Самоучитель КОМПАС-3D V19 / А. А. Герасимов. — СПб : BHV, 2021. — 624 c. — Текст : непосредственный.

# ПРИЛОЖЕНИЕ

# Код программы

Timer.hpp

1. #ifndef TIMER_H
2. #define TIMER_H
4. /*
5. * Класс таймера
6. * Использован улучшенный алгоритм таймера на millis
7. * Обеспечивает кратные интервалы и защиту от пропусков и переполнений
8. *
9. */
10. class Timer
11. {
12. public:
13. Timer( uint32_t interval ); //!< Конструктор
14. void setInterval( uint32_t interval ); //!< Выставляет интервал срабатывания таймера
15. boolean isReady(); //!< Возвращает true, когда пришло время
16. void reset(); //!< Ручной сброс таймера
17. void stop(); //!< Остановка таймера
18. void start(); //!< Запуск таймера
19. bool getState();
21. private:
22. uint32_t m_timer = 0;
23. uint32_t m_interval = 0;
24. bool m_status = true;
25. };
27. Timer::Timer(uint32_t interval)
28. {
29. m_interval = interval;
30. m_timer = millis();
31. }
33. void Timer::setInterval(uint32_t interval)
34. {
35. m_interval = (interval == 0) ? 10 : interval;
36. }
38. void Timer::start()
39. {
40. m_status = true;
41. m_timer = millis();
42. }
44. void Timer::stop()
45. {
46. m_status = false;
47. }
49. boolean Timer::isReady()
50. {
51. uint32_t thisMls = millis();
52. if (m_status && thisMls - m_timer >= m_interval)
53. {
54. do
55. {
56. m_timer += m_interval;
57. if (m_timer < m_interval) break;
58. } while (m_timer < thisMls - m_interval);
59. return true;
60. }
61. else
62. {
63. return false;
64. }
65. }
67. void Timer::reset() {
68. m_timer = millis();
69. }
71. bool Timer::getState()
72. {
73. return m_status;
74. }
76. #endif

ledStrip.hpp

1. #ifndef LED_STRIP_H
2. #define LED_STRIP_H
4. #include "settings.hpp"
5. #include <FastLED.h>
7. /*
8. * Класс ленты адресных светодиодов
9. *
10. */
13. class LedStrip
14. {
15. public:
16. LedStrip(); //!< Конструктор
17. void ledOn( uint8_t pin, uint8_t r, uint8_t g, uint8_t b ); //!< Включить светодиод. pin - позиция светодиода. r/g/b - цвет (0-255)
18. void ledOff( uint8_t pin ); //!< Выключить светодиод. pin - позиция светодиода
20. private:
21. CRGB leds[LED_COUNT];
22. };
24. LedStrip::LedStrip()
25. {
26. FastLED.addLeds <WS2812, LED_PIN, GRB>(leds, LED_COUNT).setCorrection(TypicalLEDStrip);
27. FastLED.setBrightness( BRIGHTNESS );
28. for( int i = 0 ; i < LED_COUNT; ++i )
29. leds[i] = CRGB(0, 0, 0);
30. FastLED.show();
31. Serial.println(F("LedStrip init"));
32. }
34. void LedStrip::ledOn( uint8_t pin, uint8_t r, uint8_t g, uint8_t b )
35. {
36. //Serial.print( "Led ON (pin / R;G;B): " );
37. //Serial.print( pin );
38. //Serial.print( " / " );
39. //Serial.print( r );
40. //Serial.print( ";" );
41. //Serial.print( g );
42. //Serial.print( ";" );
43. //Serial.println( b );
45. leds[pin] = CRGB(r, g, b);
46. FastLED.show();
47. }
49. void LedStrip::ledOff( uint8_t pin )
50. {
51. //Serial.print( "Led OFF (pin): " );
52. //Serial.println( pin );
53. leds[pin] = CRGB(0, 0, 0);
54. FastLED.show();
55. }
57. #endif

Pump.hpp

1. #ifndef PUMP_H
2. #define PUMP_H
4. #include "settings.hpp"
5. #include "timer.hpp"
7. /*
8. * class Pump - Класс помпы
9. */
11. class Pump
12. {
13. public:
14. Pump( int pin ); //!< Конструктор. pin - Пин питания на помпу
15. void pumpStart( uint32_t milli = DEFAULT_FINISH_TIMER ); //!< Включить помпу на milli времени (мс)
16. void pumpStartWithoutTimer();
17. void pumpStop(bool justNow=false); //!< Выключить помпу
18. uint8_t getState(); //!< Получить состояние помпы (BUSY, READY)
19. bool isPouring();
20. bool isFinishedPoured();
22. void pumpCheck(); //!< Метод, который следует положить в loop(). Нужен для своевременного отключения по таймеру
24. private:
25. Timer * startDelayTimer;
26. Timer * finishTimer;
27. Timer * finishDelayTimer;
28. int m_pompPin;
29. enum{ BUSY = 0, READY = 1 } m_state;
30. };
32. Pump::Pump( int pin )
33. {
34. startDelayTimer = new Timer( DEFAULT_DELAY_TIMER );
35. finishTimer = new Timer( DEFAULT_FINISH_TIMER );
36. finishDelayTimer = new Timer( DEFAULT_DELAY_TIMER );
37. m_state = READY;
38. m_pompPin = pin;
39. Serial.println(F("Pump init"));
41. finishTimer->stop();
42. startDelayTimer->stop();
43. finishDelayTimer->stop();
44. }
46. void Pump::pumpStart( uint32_t milli )
47. {
48. if ( m_state == BUSY )
49. {
50. Serial.println(F("Pump BUSY"));
51. return;
52. }
53. m_state = BUSY;
54. startDelayTimer->start();
55. finishTimer->stop();
56. finishDelayTimer->stop();
57. finishTimer->setInterval( milli );
58. Serial.println(F("Pump PRE-START"));
59. }
61. void Pump::pumpStartWithoutTimer()
62. {
63. digitalWrite( m_pompPin, HIGH );
64. m_state = BUSY;
65. }
67. void Pump::pumpStop( bool justNow )
68. {
69. digitalWrite( m_pompPin, LOW );
70. Serial.println(F("Pump stoped"));
72. finishTimer->stop();
73. startDelayTimer->stop();
74. finishDelayTimer->start();
76. if ( justNow )
77. {
78. finishDelayTimer->stop();
79. m_state = READY;
80. }
81. }
83. uint8_t Pump::getState()
84. {
85. return m_state;
86. }
88. bool Pump::isPouring()
89. {
90. if ( startDelayTimer->getState() == false )
91. return true;
92. return false;
93. }
95. bool Pump::isFinishedPoured()
96. {
97. if ( finishTimer->getState() == false )
98. return true;
99. return false;
100. }
102. void Pump::pumpCheck()
103. {
104. if ( startDelayTimer->isReady() )
105. {
106. startDelayTimer->stop();
107. finishTimer->start();
108. finishDelayTimer->stop();
110. digitalWrite( m_pompPin, HIGH );
111. Serial.println(F("Pump started"));
112. }
114. if ( finishTimer->isReady() )
115. pumpStop();
117. if ( finishDelayTimer->isReady() )
118. {
119. startDelayTimer->stop();
120. finishTimer->stop();
121. finishDelayTimer->stop();
122. m_state = READY;
123. }
124. }
126. #endif

servoCrane.hpp

1. #ifndef SERVO_CRANE_H
2. #define SERVO_CRANE_H
4. #include <Servo.h>
6. class ServoCrane
7. {
8. public:
9. ServoCrane( uint8_t pin );
10. void rotate( uint8_t angle );
11. uint8_t getCurrentAngle();
12. private:
13. Servo * p_servo;
14. uint8_t m_currentAngle;
15. };
17. ServoCrane::ServoCrane( uint8_t pin )
18. {
19. p_servo = new Servo();
20. m_currentAngle = 180;
21. p_servo->attach( pin );
22. p_servo->write( m_currentAngle );
24. Serial.println(F("ServoCrane init"));
25. }
27. void ServoCrane::rotate( uint8_t angle )
28. {
29. if ( angle > 180 || angle < 0 )
30. return;
31. p_servo->write( angle );
32. m_currentAngle = angle;
33. Serial.println("ServoCrane rotate to " + angle);
34. }
36. uint8_t ServoCrane::getCurrentAngle()
37. {
38. return m_currentAngle;
39. }
43. #endif

Display.hpp

1. #ifndef DISPLAY_H
2. #define DISPLAY_H
4. #include "mem.hpp"
5. #include <Adafruit_GFX.h>
6. #include <Adafruit_SSD1306.h>
8. String utf8rus(String source);
9. //String printPGM(byte idx);
11. class Display
12. {
13. public:
14. Display();
15. void printRandToast();
16. void printInfo( uint16_t volume, uint8_t mode );
17. void printInfo( uint32_t volume );
18. private:
19. Adafruit_SSD1306 * display;
20. };
22. Display::Display()
23. {
24. display = new Adafruit_SSD1306(128, 32, &Wire);
25. display->begin(SSD1306_SWITCHCAPVCC, 0x3C);
26. display->clearDisplay();
27. display->display();
29. Serial.println(F("Display init"));
31. display->setTextSize(2);
32. display->setTextColor(SSD1306_WHITE);
33. display->setCursor(0,0);
34. display->println(utf8rus("Робот\nРазливайка"));
35. display->display();
36. }
38. void Display::printRandToast()
39. {
40. display->setTextSize(2);
41. display->clearDisplay();
42. display->display();
43. display->setCursor(0,0);
44. display->println(utf8rus(printPGM(random(0, 34))));
45. display->display();
46. }
48. void Display::printInfo( uint16_t volume, uint8_t mode )
49. {
50. display->setTextSize(4);
51. display->clearDisplay();
52. display->display();
53. display->setCursor(0,0);
54. display->println( volume );
55. display->setCursor(100,0);
57. if ( mode == 0 )
58. display->println( "M" );
59. else if ( mode == 1 )
60. display->println( "A" );
61. else if ( mode == 2 )
62. display->println( "S" );
64. display->display();
65. }
67. void Display::printInfo( uint32_t volume )
68. {
69. display->setTextSize(4);
70. display->clearDisplay();
71. display->display();
72. display->setCursor(0,0);
73. display->println( volume );
74. display->display();
75. }
78. String utf8rus(String source)
79. {
80. int i,k;
81. String target;
82. unsigned char n;
83. char m[2] = { '0', '\0' };
85. k = source.length(); i = 0;
87. while (i < k) {
88. n = source[i]; i++;
90. if (n >= 0xC0) {
91. switch (n) {
92. case 0xD0: {
93. n = source[i]; i++;
94. if (n == 0x81) { n = 0xA8; break; }
95. if (n >= 0x90 && n <= 0xBF) n = n + 0x30;
96. break;
97. }
98. case 0xD1: {
99. n = source[i]; i++;
100. if (n == 0x91) { n = 0xB8; break; }
101. if (n >= 0x80 && n <= 0x8F) n = n + 0x70;
102. break;
103. }
104. }
105. }
106. m[0] = n; target = target + String(m);
107. }
108. return target;
109. }
111. #endif

Display_debug.hpp

1. #ifndef DISPLAY_H
2. #define DISPLAY_H
4. #include "mem.hpp"
6. String utf8rus(String source);
7. String printPGM(byte idx);
9. class Display
10. {
11. public:
12. Display();
13. void printRandToast();
14. void printInfo( uint16_t volume, uint8_t mode );
15. };
17. Display::Display()
18. {
19. Serial.println(F("Display init"));
20. Serial.println(F("Робот\nРазливайка"));
21. }
23. void Display::printRandToast()
24. {
25. Serial.println( printPGM(random( 0, 20 ) ) );
26. }
28. void Display::printInfo( uint16_t volume, uint8_t mode )
29. {
30. String res;
31. res = volume;
32. res += " ";
34. if ( mode == 0 )
35. res += "M";
36. else if ( mode == 1 )
37. res += "A";
38. else if ( mode == 2 )
39. res += "S";
41. Serial.println( res );
42. }
45. void Display::printInfo( uint32_t volume )
46. {
47. Serial.println( volume );
48. }
51. String utf8rus(String source)
52. {
53. int i,k;
54. String target;
55. unsigned char n;
56. char m[2] = { '0', '\0' };
58. k = source.length(); i = 0;
60. while (i < k) {
61. n = source[i]; i++;
63. if (n >= 0xC0) {
64. switch (n) {
65. case 0xD0: {
66. n = source[i]; i++;
67. if (n == 0x81) { n = 0xA8; break; }
68. if (n >= 0x90 && n <= 0xBF) n = n + 0x30;
69. break;
70. }
71. case 0xD1: {
72. n = source[i]; i++;
73. if (n == 0x91) { n = 0xB8; break; }
74. if (n >= 0x80 && n <= 0x8F) n = n + 0x70;
75. break;
76. }
77. }
78. }
79. m[0] = n; target = target + String(m);
80. }
81. return target;
82. }
84. #endif

Slot.hpp

1. #ifndef SLOT_H
2. #define SLOT_H
4. #include "timer.hpp"
5. #include "servocrane.hpp"
6. #include "pump.hpp"
7. #include "ledstrip.hpp"
9. class Slot
10. {
11. public:
12. Slot( LedStrip * ledStrip, Pump * pump, ServoCrane * servo, uint8_t btnPin, uint8_t slotID, uint8_t slotAngle, uint16_t * glassVolume );
13. void slotFirstCheck();
14. void slotSecondCheck();
15. void slotThirdCheck();
16. uint8_t getState();
18. private:
19. Timer * btnTimer;
20. bool btnState;
21. ServoCrane * m_servo;
22. Pump * p_pump;
23. LedStrip * p_ledStrip; //!< Указатель на сервис ленты светодиодов
24. uint8_t m_btnPin; //!< Номер пина концевика
25. uint8_t m_slotID; //!< ID слота. Должен совпадать с индексом светодиода
26. uint8_t m_slotAngle; //!< Угол расположения слота (0-180)
27. enum{ NO_GLASS, EMPTY, NEXT, PROCESS, READY } m_state; //!< Статус слота
28. uint16_t * p_glassVolume;
29. };
31. Slot::Slot( LedStrip * ledStrip, Pump * pump, ServoCrane * servo, uint8_t btnPin, uint8_t slotID, uint8_t slotAngle, uint16_t * glassVolume )
32. {
33. btnTimer = new Timer( 100 );
34. btnState = false;
35. p_ledStrip = ledStrip;
36. p_pump = pump;
37. m_servo = servo;
38. m_btnPin = btnPin;
39. m_slotID = slotID;
40. m_slotAngle = slotAngle;
41. m_state = NO_GLASS;
42. p_glassVolume = glassVolume;
43. }
45. void Slot::slotFirstCheck()
46. {
47. /*
48. * Этап #1. Проверяем нажатие концевика. Включаем красный светодиод если рюмку только
49. * что поставили. Выключаем светодиод, если рюмку убрали. В ручном режиме этот режим нужно включить в loop отдельно,
50. * чтобы светодиоды закагарились красным до начала разлива
51. *
52. */
53. // Если концевик НЕ нажат
55. if ( btnTimer->isReady() )
56. btnState = digitalRead( m_btnPin );
58. if ( btnState )
59. {
60. // У сервопривода будет поле текущего угла. Нужно проверить - если угол серво равен углу слота и статус слота = PROCESS, значит стопаем помпу
61. if ( m_servo->getCurrentAngle() == m_slotAngle && ( m_state == PROCESS || m_state == NEXT ) )
62. {
63. p_pump->pumpStop( false );
64. }
66. if ( m_state != NO_GLASS )
67. {
68. m_state = NO_GLASS;
69. p_ledStrip->ledOff( m_slotID );
70. }
71. }
72. // Если концевик нажат
73. else if ( !btnState )
74. {
75. if ( m_state == NO_GLASS )
76. {
77. m_state = EMPTY;
78. p_ledStrip->ledOn( m_slotID, 255, 0, 0 );
79. }
80. }
81. }
83. void Slot::slotSecondCheck()
84. {
85. /*
86. * Этап #2. После первой проверки проверяем статус. Если рюмка налита красим светодиод в зеленый.
87. *
88. */
90. if ( m_state == PROCESS && p_pump->isFinishedPoured() )
91. {
92. m_state = READY;
93. p_ledStrip->ledOn( m_slotID, 0, 255, 0 );
94. }
96. }
98. void Slot::slotThirdCheck()
99. {
100. /*
101. * Этап #3. После второй проверки проверяем статус. Если рюмка пустует - пытаемся запросить серво и помпу налить в нее.
102. *
103. */
104. if ( m_state == EMPTY && p_pump->getState() != 0 /* m_servo->getState() != BUSY */ )
105. {
106. m_state = NEXT;
107. m_servo->rotate( m_slotAngle );
108. p_pump->pumpStart( ONE_HUNDRED_PER_SECOND / 100 * (*p_glassVolume) );
109. p_ledStrip->ledOn( m_slotID, 0, 0, 255 );
110. }
112. if ( m_state == NEXT && p_pump->isPouring() )
113. {
114. m_state = PROCESS;
115. p_ledStrip->ledOn( m_slotID, 255, 255, 0 );
116. }
118. }
120. uint8_t Slot::getState()
121. {
122. return m_state;
123. }
125. #endif

Brain.hpp

1. #ifndef BRAIN_H
2. #define BRAIN_H
4. #include "timer.hpp"
5. #include "settings.hpp"
6. #include <EncButton.h>
8. #include "slot.hpp"
9. #include "servocrane.hpp"
10. #include "pump.hpp"
11. #include "ledstrip.hpp"
12. #include "display.hpp"
16. const uint8_t BTN_SLOT_PINS[SLOT_COUNT] { A0, A1, A2, A3, 2, 7 };
17. const uint8_t SLOT_IDS[SLOT_COUNT] { 0, 1, 2, 3, 4, 5 };
18. const uint8_t SLOT_ANGLES[SLOT_COUNT] { 175, 143, 109, 71, 35, 5 };
20. class Brain
21. {
22. public:
23. Brain();
24. void tick();
25. private:
26. void changeAutoManualMode();
27. void changeServiceMode();
28. void incGlassVolume();
29. void decGlassVolume();
30. void mainBtnPressed();
31. void mainBtnReleased();
32. void mainBtnClick();
33. void encClicked();
35. enum{MANUAL, AUTO, SERVICE} m_mode;
36. uint16_t m_glassVolume;
37. enum{ BUSY, READY } m_status;
38. enum{ STARTED, FINISHED } m_manualModeFlag;
39. bool m_toastFlag;
41. bool isStarted;
42. Timer * p_starterTimer;
43. uint32_t p_serviceTime;
44. ServoCrane * p_servo;
45. Pump * p_pump;
46. LedStrip * p_ledStrip;
47. Slot ** p_slots;
48. Display * p_display;
49. EncButton<EB_TICK, ENC_A_PIN, ENC_B_PIN, ENC_BTN_PIN> * p_encoder;
50. EncButton<EB_TICK, MAIN_BTN_PIN> * p_button;
51. };
53. Brain::Brain()
54. {
55. p_starterTimer = new Timer( 3000 );
56. isStarted = false;
58. m_mode = MANUAL;
59. m_glassVolume = 20;
60. m_toastFlag = false;
61. p_servo = new ServoCrane( SERVO_PIN );
62. p_pump = new Pump( PUMP_PIN );
63. p_ledStrip = new LedStrip();
64. p_slots = new Slot * [SLOT_COUNT];
66. for ( int i = 0; i < SLOT_COUNT; ++i )
67. p_slots[i] = new Slot( p_ledStrip, p_pump, p_servo, BTN_SLOT_PINS[i], SLOT_IDS[i], SLOT_ANGLES[i], &m_glassVolume );
69. p_display = new Display();
71. p_encoder = new EncButton<EB_TICK, ENC_A_PIN, ENC_B_PIN, ENC_BTN_PIN>;
72. p_button = new EncButton<EB_TICK, MAIN_BTN_PIN>;
74. m_manualModeFlag = FINISHED;
75. }
77. void Brain::tick()
78. {
79. if ( !isStarted )
80. {
81. isStarted = p_starterTimer->isReady();
82. return;
83. }
85. m_status = READY;
86. for ( int i = 0; i < SLOT_COUNT; ++i )
87. if ( p_slots[i]->getState() == 2 || p_slots[i]->getState() == 3 )
88. {
89. m_status = BUSY;
90. m_manualModeFlag = STARTED;
91. if ( !m_toastFlag )
92. p_display->printRandToast();
93. m_toastFlag = true;
94. break;
95. }
97. if ( m_status == READY && p_servo->getCurrentAngle() != 180 && m_mode != SERVICE && p_pump->getState() != 0 )
98. p_servo->rotate( 180 );
100. if ( m_status == READY && p_servo->getCurrentAngle() == 180 && m_mode != SERVICE && p_pump->getState() != 0 )
101. {
102. m_manualModeFlag = FINISHED;
103. m_toastFlag = false;
104. }
106. p_encoder->tick();
107. p_button->tick();
108. p_pump->pumpCheck();
110. if ( m_status == READY )
111. {
112. if ( p_encoder->rightH() || p_encoder->leftH() )
113. changeAutoManualMode();
114. else if ( p_encoder->held() )
115. changeServiceMode();
116. else if ( p_encoder->right() )
117. incGlassVolume();
118. else if ( p_encoder->left() )
119. decGlassVolume();
120. else if ( p_encoder->click() )
121. encClicked();
122. else if ( p_button->press() )
123. mainBtnPressed();
124. else if ( p_button->release() )
125. mainBtnReleased();
126. else if ( p_button->click() )
127. mainBtnClick();
128. }
130. if ( m_mode == MANUAL )
131. {
132. for ( int i = 0; i < SLOT_COUNT; ++i )
133. p_slots[i]->slotFirstCheck();
134. if ( m_manualModeFlag == STARTED )
135. {
136. for ( int i = 0; i < SLOT_COUNT; ++i )
137. p_slots[i]->slotSecondCheck();
138. for ( int i = 0; i < SLOT_COUNT; ++i )
139. p_slots[i]->slotThirdCheck();
140. }
141. }
142. else if ( m_mode == AUTO )
143. {
144. for ( int i = 0; i < SLOT_COUNT; ++i )
145. p_slots[i]->slotFirstCheck();
146. for ( int i = 0; i < SLOT_COUNT; ++i )
147. p_slots[i]->slotSecondCheck();
148. for ( int i = 0; i < SLOT_COUNT; ++i )
149. p_slots[i]->slotThirdCheck();
150. }
151. else if ( m_mode == SERVICE )
152. {
153. for ( int i = 0; i < SLOT_COUNT; ++i )
154. p_slots[i]->slotFirstCheck();
155. }
156. }
158. void Brain::changeAutoManualMode()
159. {
160. Serial.println(F("Mode changed"));
161. if ( m_mode != SERVICE )
162. {
163. if ( m_mode == AUTO )
164. m_mode = MANUAL;
165. else if ( m_mode == MANUAL )
166. m_mode = AUTO;
168. p_display->printInfo( m_glassVolume, m_mode );
169. }
170. }
172. void Brain::changeServiceMode()
173. {
174. Serial.println(F("Mode changed"));
175. if ( m_mode == AUTO || m_mode == MANUAL)
176. {
177. m_mode = SERVICE;
178. p_display->printInfo( p_servo->getCurrentAngle(), m_mode );
179. }
180. else if ( m_mode == SERVICE && !p_button->hold() )
181. {
182. m_mode = MANUAL;
183. p_display->printInfo( m_glassVolume, m_mode );
184. }
185. }
187. void Brain::incGlassVolume()
188. {
189. if ( m_mode == AUTO || m_mode == MANUAL )
190. {
191. m_glassVolume = m_glassVolume >= 250 ? 250 : m_glassVolume + 1;
192. p_display->printInfo( m_glassVolume, m_mode );
193. }
195. else if ( m_mode == SERVICE )
196. {
197. p_servo->rotate( p_servo->getCurrentAngle() + 1 );
198. p_display->printInfo( p_servo->getCurrentAngle(), m_mode );
199. }
200. }
202. void Brain::decGlassVolume()
203. {
204. if ( m_mode == AUTO || m_mode == MANUAL )
205. {
206. m_glassVolume = m_glassVolume <= 5 ? 5 : m_glassVolume - 1;
207. p_display->printInfo( m_glassVolume, m_mode );
208. }
210. else if ( m_mode == SERVICE )
211. {
212. p_servo->rotate( p_servo->getCurrentAngle() - 1 );
213. p_display->printInfo( p_servo->getCurrentAngle(), m_mode );
214. }
215. }
217. void Brain::mainBtnPressed()
218. {
219. Serial.println(F( "MainBTN PRESSED" ) );
220. if ( m_mode == AUTO )
221. return;
222. else if ( m_mode == MANUAL )
223. return;
224. else if ( m_mode == SERVICE )
225. {
226. p_serviceTime = millis();
227. p_pump->pumpStartWithoutTimer();
228. }
229. }
231. void Brain::mainBtnReleased()
232. {
233. Serial.println(F("MainBTN RELEASED"));
234. if ( m_mode == SERVICE )
235. {
236. p_display->printInfo( ( millis() - p_serviceTime ) % 100000 );
237. p_pump->pumpStop();
238. }
239. }
241. void Brain::mainBtnClick()
242. {
243. if ( m_mode == MANUAL )
244. {
245. m_manualModeFlag = STARTED;
246. }
247. }
249. void Brain::encClicked()
250. {
251. if ( ( m_mode == AUTO || m_mode == MANUAL ) && m_manualModeFlag == FINISHED )
252. p_display->printInfo( m_glassVolume, m_mode );
254. else if ( m_mode == SERVICE && m_manualModeFlag == FINISHED )
255. p_display->printInfo( p_servo->getCurrentAngle(), m_mode );
256. }
258. #endif

Setting.hpp

1. #ifndef SETTINGS_H
2. #define SETTINGS_H
5. //Общая настройка
6. #define SLOT_COUNT 6
7. #define SERVO_PIN 5
8. #define PUMP_PIN 6
11. //Настройка элементов управления
12. #define MAIN_BTN_PIN 4
13. #define ENC_BTN_PIN 11
14. #define ENC_A_PIN 10
15. #define ENC_B_PIN 8
18. //Настройка светодиодной ленты
19. #define BRIGHTNESS 255 //!< Яркость светодиодов
20. #define LED_PIN 3 //!< Пин подключения светодиодной ленты
21. #define LED_COUNT 6 //!< Кол-во светодиодов в ленте
24. //Настройка помпы
25. #define DEFAULT_DELAY_TIMER 1500
26. #define DEFAULT_FINISH_TIMER 2000 //!< Время по умолчанию, которое будет отрабатывать мотор при pumpStart( uint32_t seconds )
27. #define ONE_HUNDRED_PER_SECOND 12900
30. #endif

Mem.hpp

1. #ifndef MEM_H
2. #define MEM_H
4. const char str1[] PROGMEM = " ЗА\n ЛЮБОВЬ";
5. const char str2[] PROGMEM = " ЧТОБЫ\n ВСЕ";
6. const char str3[] PROGMEM = " ЗА ВСЁ\n ХОРОШЕЕ";
7. const char str4[] PROGMEM = " ЗА\n ЗДОРОВЬЕ";
8. const char str5[] PROGMEM = " ЗА\n ДЕТЕЙ";
9. const char str6[] PROGMEM = "ЗА\nРОДИТЕЛЕЙ";
10. const char str7[] PROGMEM = " ЗА\n ДРУЖБУ";
11. const char str8[] PROGMEM = " БЫТЬ\n ДОБРУ";
12. const char str9[] PROGMEM = " ЗА МИР";
13. const char str10[] PROGMEM = " НЕ\n ЧОКАЯСЬ";
14. const char str11[] PROGMEM = " ЗА\n ЖИЗНЬ";
15. const char str12[] PROGMEM = " ЗА ДАМ";
16. const char str13[] PROGMEM = " ЗА\n РОССИЮ";
17. const char str14[] PROGMEM = " ЗА\n МУЖЧИН";
18. const char str15[] PROGMEM = " ЗА\n УДАЧУ";
19. const char str16[] PROGMEM = " ЗА НАС";
20. const char str17[] PROGMEM = " ЗА\n КРАСОТУ";
21. const char str18[] PROGMEM = " ЗА\n ДОБРОТУ";
22. const char str19[] PROGMEM = " ЗА\n ПОГОДУ";
23. const char str20[] PROGMEM = " ЗА\n ПРИРОДУ";
24. const char str21[] PROGMEM = " ЗА\n ХОЗЯИНА";
25. const char str22[] PROGMEM = " ЗА\n БУДУЩЕЕ";
26. const char str23[] PROGMEM = " ЗА\n ПАМЯТЬ";
27. const char str24[] PROGMEM = " ЗА\n ОТДЫХ";
28. const char str25[] PROGMEM = "ЗА\nНАСТРОЕНИЕ";
29. const char str26[] PROGMEM = " ЧТОБ\n СТОЯЛ";
30. const char str27[] PROGMEM = " ЗА\n ДОСТАТОК";
31. const char str28[] PROGMEM = " ЗА\n КОСМОС";
32. const char str29[] PROGMEM = " ЗА\n ТЕРПЕНИЕ";
33. const char str30[] PROGMEM = " ЗА\n МЕДВЕДЕЙ";
34. const char str31[] PROGMEM = " ЗА\n ЛОГИКУ";
35. const char str32[] PROGMEM = "ЗА\n ТРЕЗВОСТЬ";
36. const char str33[] PROGMEM = " ЗА\n УСПЕХ";
37. const char str34[] PROGMEM = " ЗА\n ПОБЕДУ";
39. const char* const names[] PROGMEM = {
40. str1, str2, str3, str4, str5,
41. str6, str7, str8, str9, str10,
42. str11, str12, str13, str14, str15,
43. str16, str17, str18, str19, str20,
44. str21, str22, str23, str24, str25,
45. str26, str27, str28, str29, str30,
46. str31, str32, str33, str34
47. };
49. String printPGM(byte idx) {
50. PGM_P p = pgm_read_word(names + idx);
51. char buf[strlen_P(p)];
52. strcpy_P(buf, p);
53. return String(buf);
54. }
56. #endif

Main.ino

1. #include "brain.hpp"
3. Brain * brain;
5. void setup() {
6. pinMode(A0, INPUT_PULLUP);
7. pinMode(A1, INPUT_PULLUP);
8. pinMode(A2, INPUT_PULLUP);
9. pinMode(A3, INPUT_PULLUP);
10. pinMode(2, INPUT_PULLUP);
11. pinMode(7, INPUT_PULLUP);
12. pinMode(4, INPUT_PULLUP);
13. pinMode(6, OUTPUT);
14. pinMode(3, OUTPUT);
15. pinMode(5, OUTPUT);
16. //digitalWrite(6, LOW);
18. Serial.begin(9600);
19. brain = new Brain();
20. }
22. void loop() {
23. brain->tick();
24. }
26. extern int __bss_end;
27. extern void *__brkval;
29. int memoryFree()
30. {
31. int freeValue;
32. if((int)__brkval == 0)
33. freeValue = ((int)&freeValue) - ((int)&__bss_end);
34. else
35. freeValue = ((int)&freeValue) - ((int)__brkval);
36. return freeValue;
37. }

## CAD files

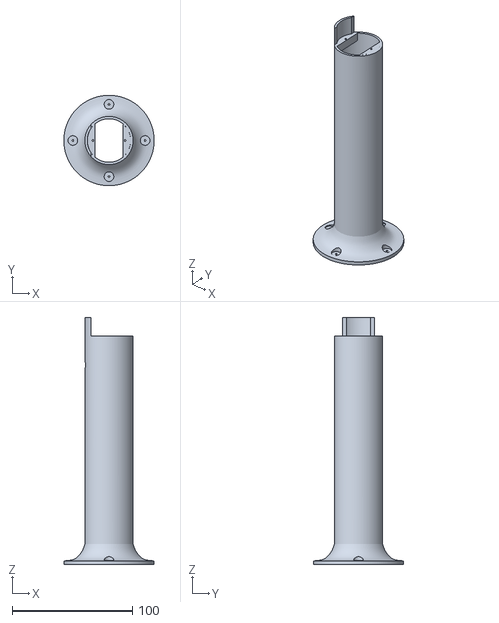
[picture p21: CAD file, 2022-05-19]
models/stl/Стойка.stl
75.0 x 75.0 x 205.0

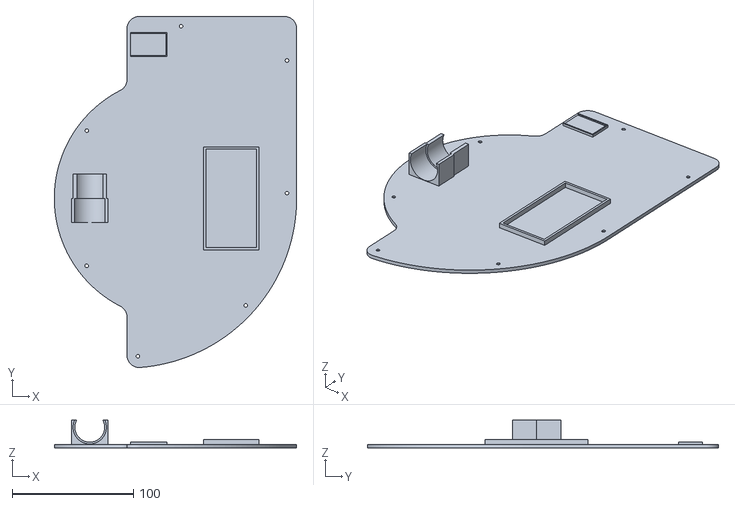
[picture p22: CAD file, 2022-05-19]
models/stl/Крышка.stl
200.0 x 289.6 x 22.9

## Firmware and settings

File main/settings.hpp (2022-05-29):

#ifndef SETTINGS_H
#define SETTINGS_H

/*
*  Файл настроек робота
*  
*/

//Общая настройка
#define SLOT_COUNT 6        //!< Кол-во слотов
#define SERVO_PIN 5         //!< Пин управления сервоприводом
#define PUMP_PIN 6          //!< Пин питания помпой


//Настройка элементов управления
#define MAIN_BTN_PIN 4      //!< Пин главной кнопки
#define ENC_BTN_PIN 11      //!< Пин кнопки энкодера
#define ENC_A_PIN 10        //!< Пин SW1 энкодера
#define ENC_B_PIN 8         //!< Пин SW2 энкодера


//Настройка светодиодной ленты
#define BRIGHTNESS 255		//!< Яркость светодиодов
#define LED_PIN 3			//!< Пин подключения светодиодной ленты
#define LED_COUNT 6			//!< Кол-во светодиодов в ленте


//Настройка помпы
#define DEFAULT_DELAY_TIMER 1500		//!< Время задержки ДО и ПОСЛЕ разлива
#define DEFAULT_FINISH_TIMER 2000	    //!< Время по умолчанию, которое будет отрабатывать мотор при pumpStart( uint32_t seconds )
#define ONE_HUNDRED_PER_SECOND 12900  	//!< Время, за которое наливается 100мл в мс


#endif

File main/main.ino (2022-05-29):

#include "brain.hpp"

Brain * brain;

void setup() {
  // Делаем подтяжку на концевики, т.к. они запаяны без подтягивающих резисторов
  pinMode(A0, INPUT_PULLUP);
  pinMode(A1, INPUT_PULLUP);
  pinMode(A2, INPUT_PULLUP);
  pinMode(A3, INPUT_PULLUP);
  pinMode(2, INPUT_PULLUP);
  pinMode(7, INPUT_PULLUP);
  pinMode(4, INPUT_PULLUP);
  pinMode(6, OUTPUT);
  pinMode(3, OUTPUT);
  pinMode(5, OUTPUT);
  
  Serial.begin(9600);
  brain = new Brain();  //!< Инициализация мозгов
}

void loop() {
  brain->tick();
}

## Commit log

2022-05-11 Класс помпы и таймера
    -Добавлен класс для работы с помпой
    -Добавлен класс таймера
2022-05-12 Класс LedStrip
    -Добавлен класс для работы с адресными светодиодами
2022-05-12 Документация LedStrip
    -Добавлена документация к LedStrip
2022-05-15 Добавлен класс ServoCrane и Slot
    -Добавлен класс Slot, отвечающий за слот. На данный момент отрабатывает большую часть логики.
    -Добавлен класс ServoCrane отвечающий за сервопривод
    -Изменена яркость светодиодов до максимально возможной
    -Время ожидания помпы перед наливом уменьшено до 1 секунды
2022-05-16 Добавлены предварительные модели сборки
2022-05-17 Демо модель
2022-05-18 Обновление моделек
2022-05-19 Предварительная версия
    -Добавлен основной класс Brain, отвечающий за логику работы механизма и меню
    -Добавлен класс Display|
    -Добавлены тосты
2022-05-19 Добавлена задержка перед началом работы
2022-05-23 Добавлен файл конфигурации
2022-05-23 Добавлена возможность задавать объем рюмки
    -Добавлена возможность задавать объем рюмки
    -Добавлено отображение времени работы помпы в режиме сервиса
2022-05-26 Оптимизация
2022-05-26 Обновление демо
2022-05-26 Добавлено демо
2022-05-29 Рефакторинг
2022-05-30 Добавлена схема подключения в документацию
2022-05-30 add algorithm flowchart
2022-05-30 change docs strcuture and add new part
    New part is algorithm flowchart describe
